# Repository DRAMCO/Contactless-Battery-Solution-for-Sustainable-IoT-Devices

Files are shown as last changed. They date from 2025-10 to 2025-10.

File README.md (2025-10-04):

# Contactless Battery Solution for Sustainable IoT Devices: Assessment of Environmental Impact

Supplementary material for "MDPI Electronics special issue Wireless Power Transfer Systems: Design and Implementation"

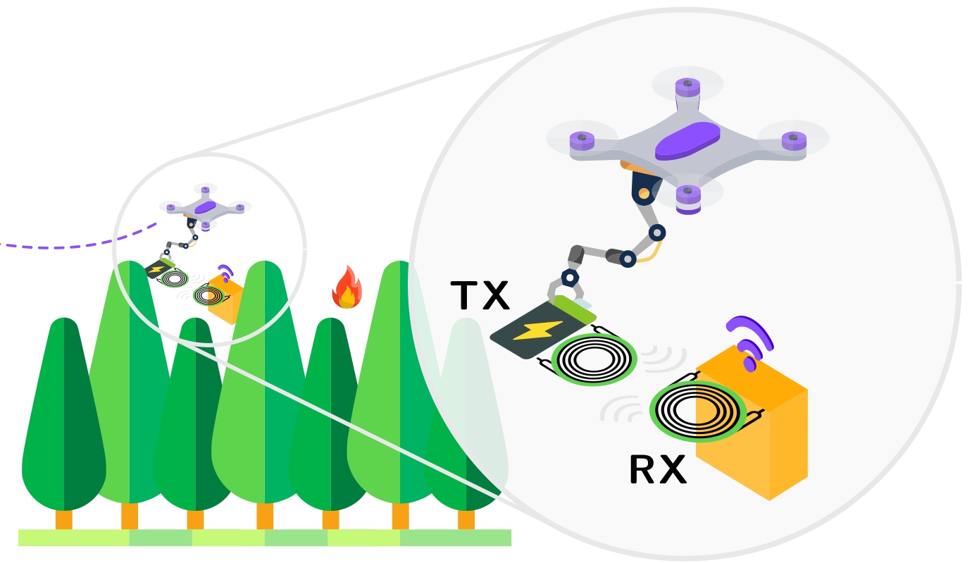
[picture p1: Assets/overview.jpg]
overview


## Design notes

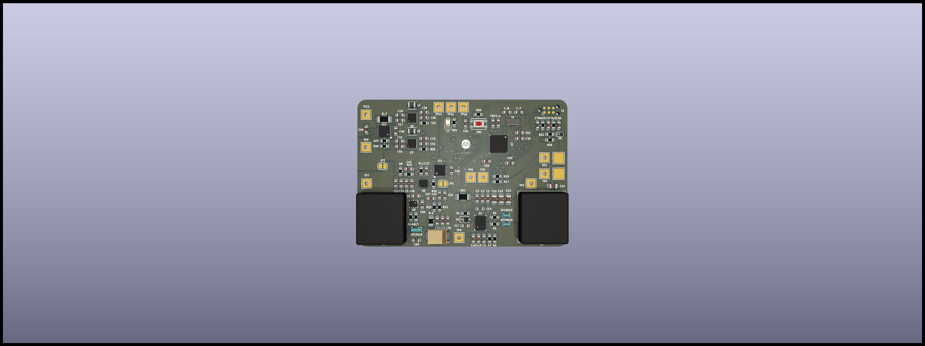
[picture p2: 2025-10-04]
Hardware/wpt_transmitter/driver_prereg_combined.png

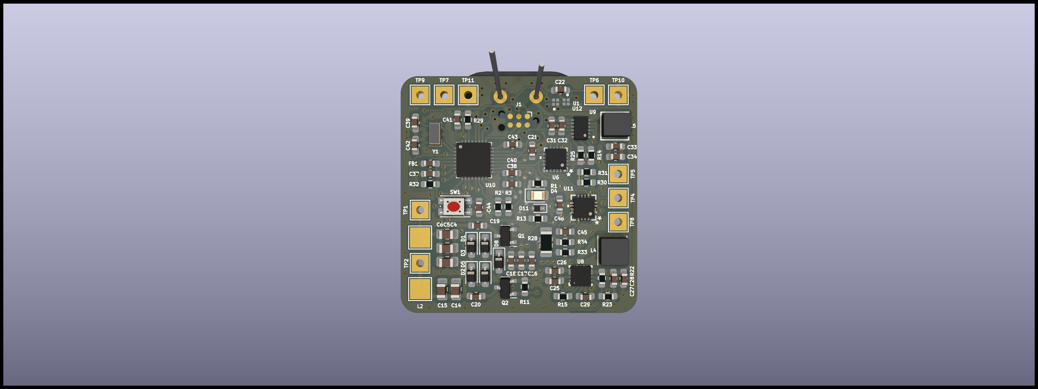
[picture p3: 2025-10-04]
Hardware/wpt_receiver/wpt_receiver.png

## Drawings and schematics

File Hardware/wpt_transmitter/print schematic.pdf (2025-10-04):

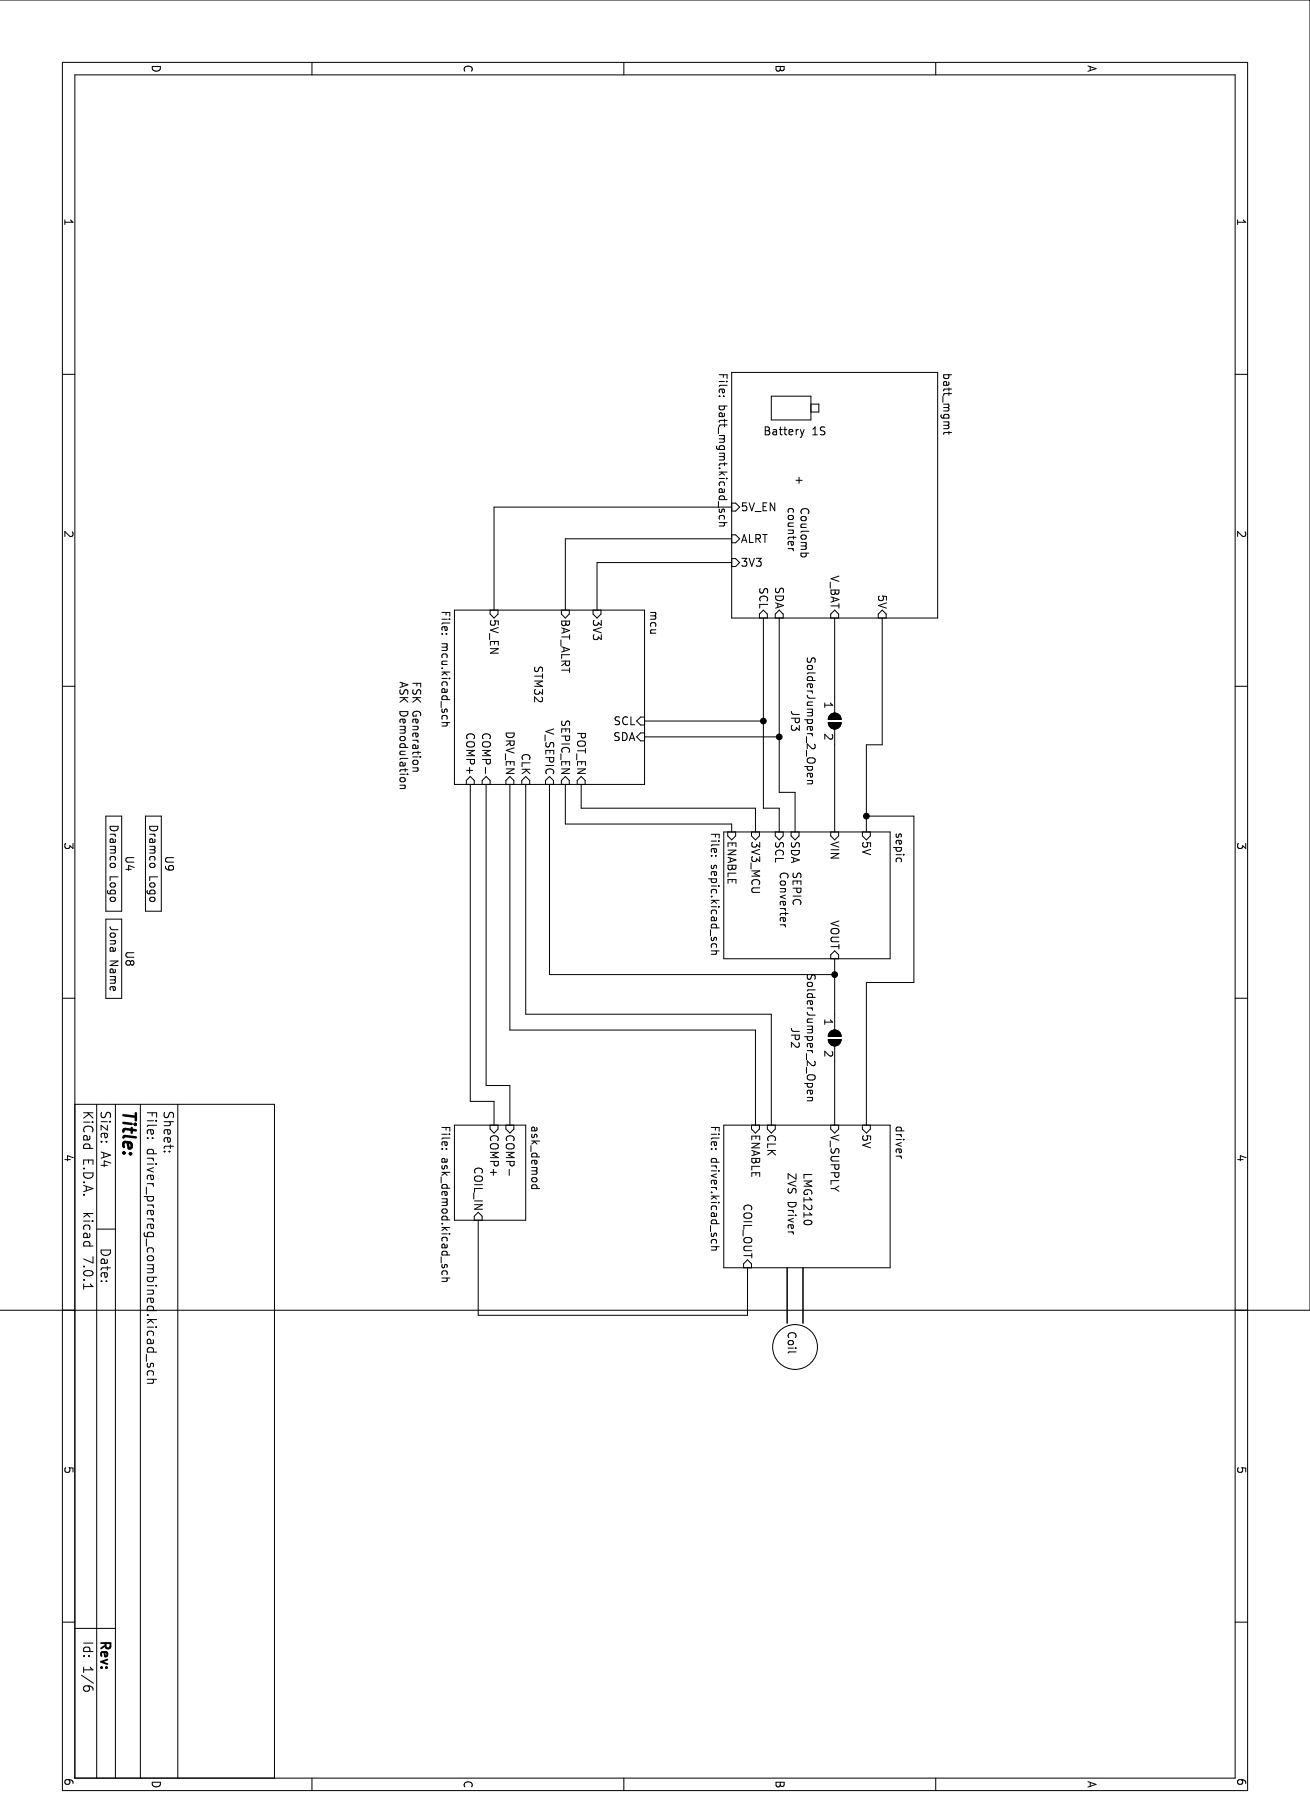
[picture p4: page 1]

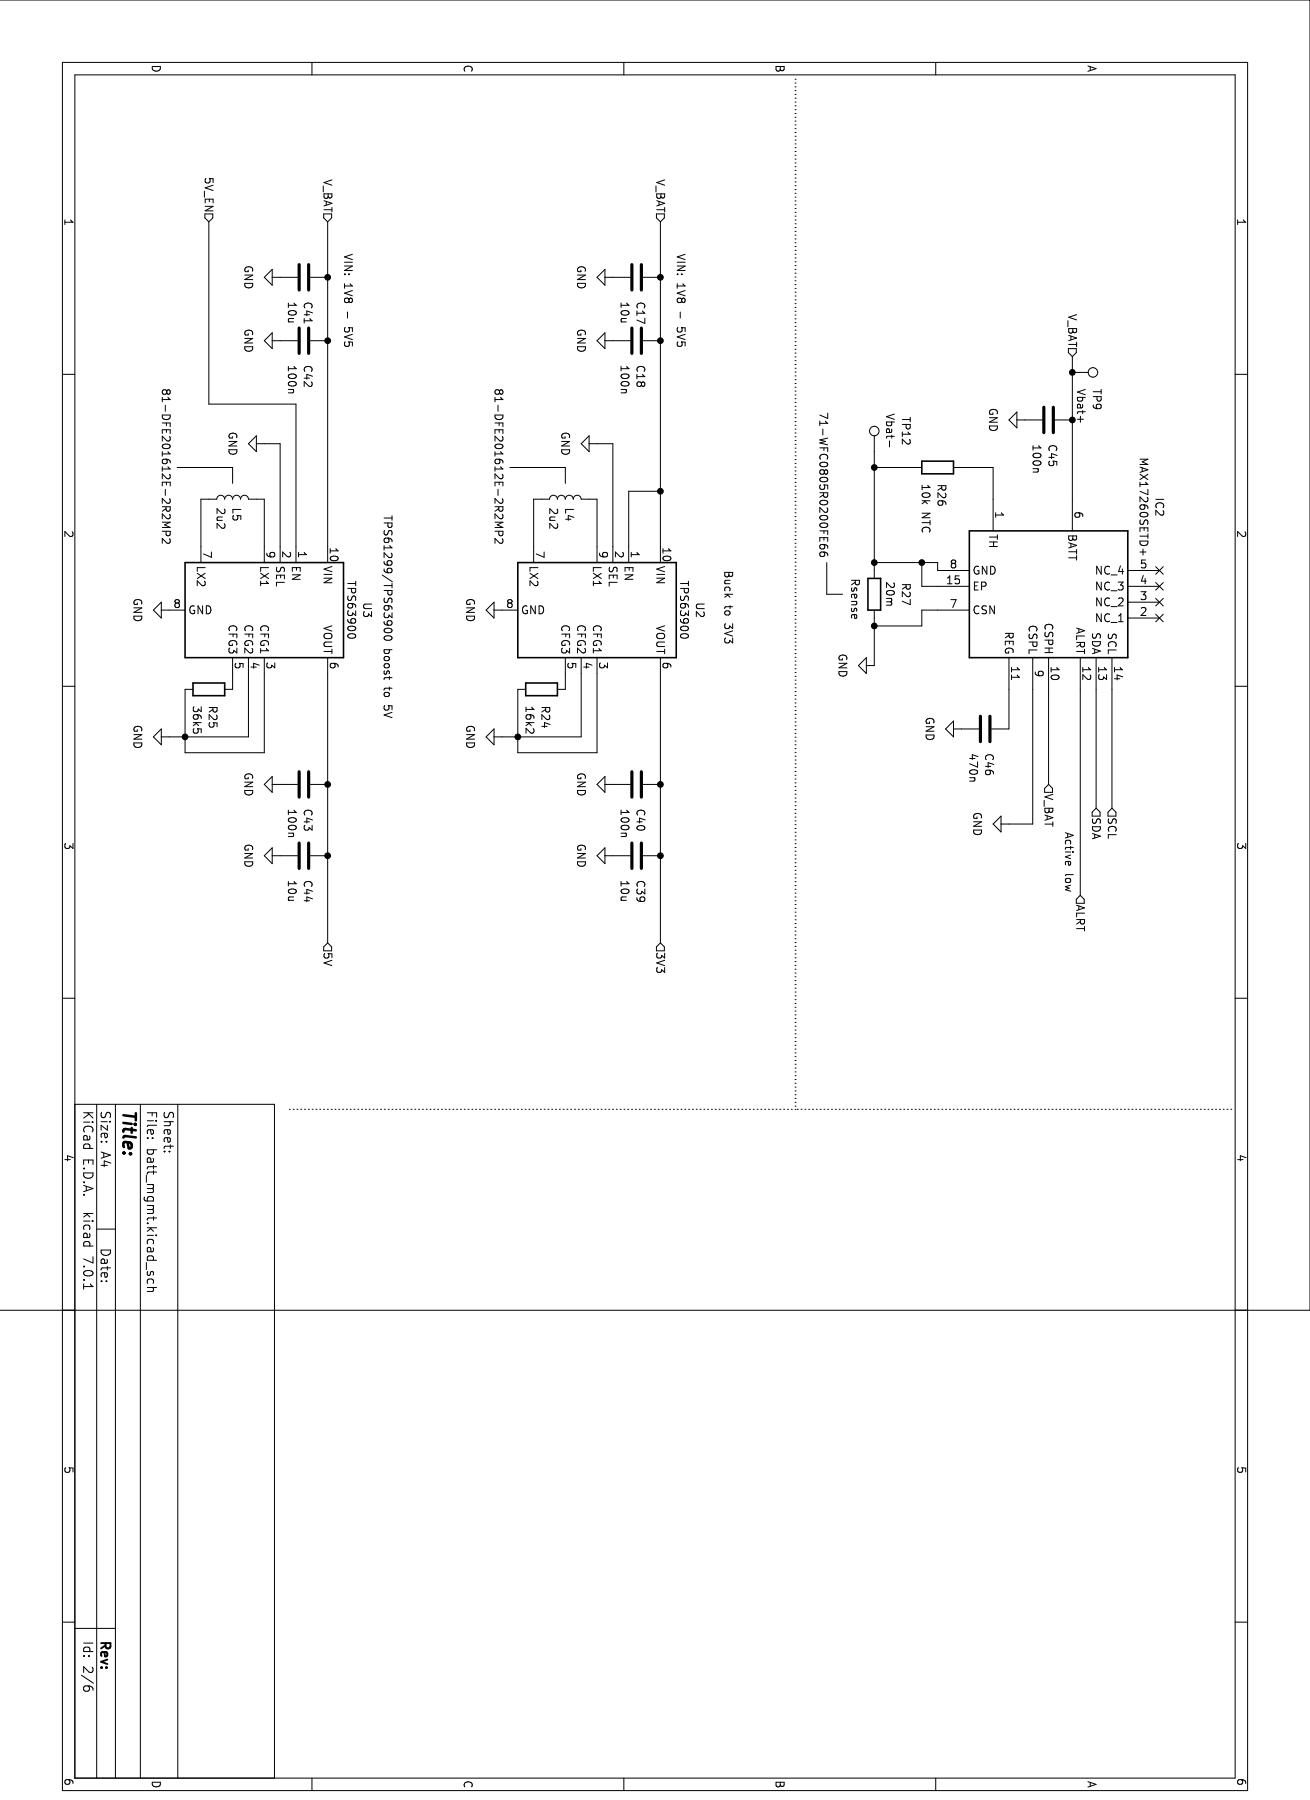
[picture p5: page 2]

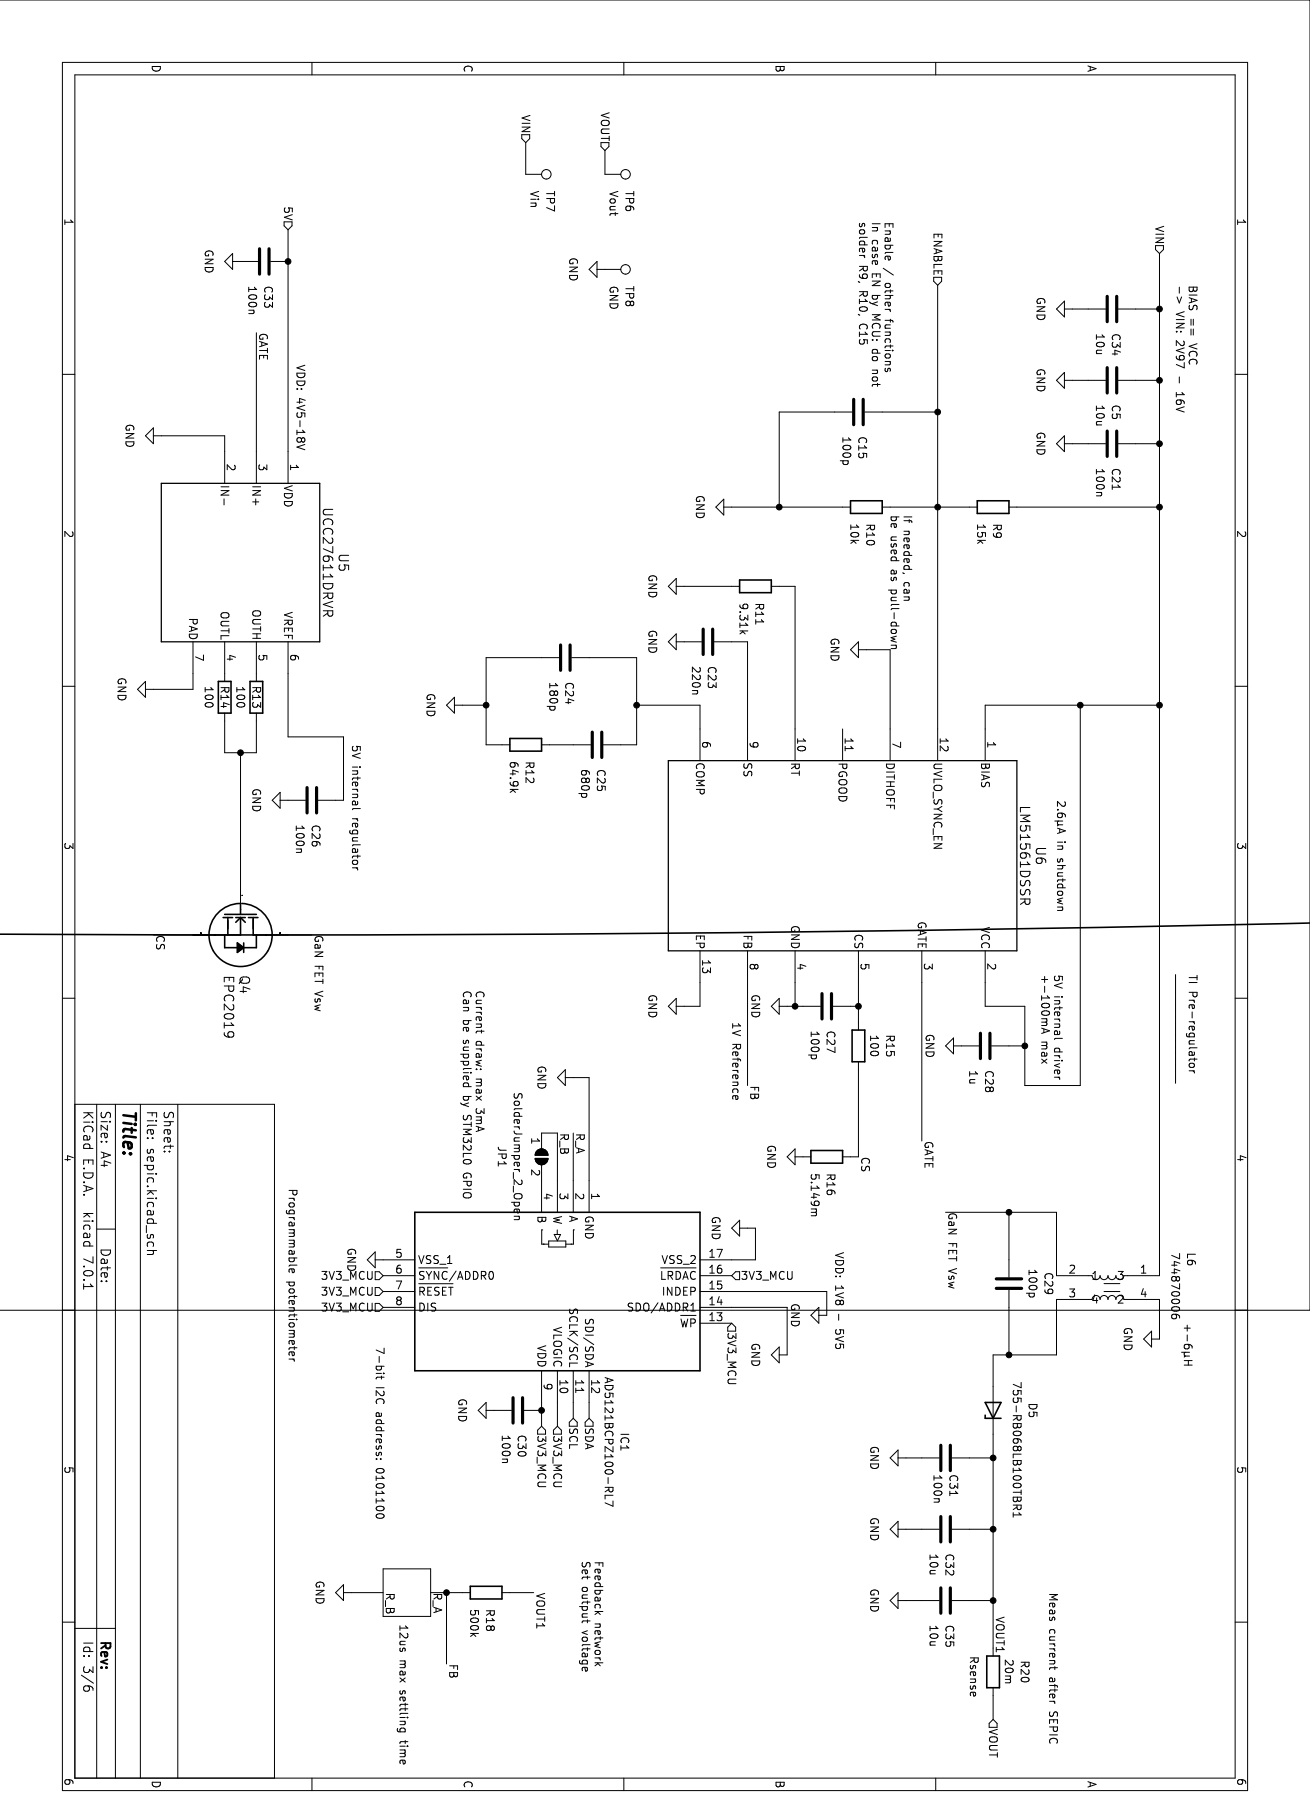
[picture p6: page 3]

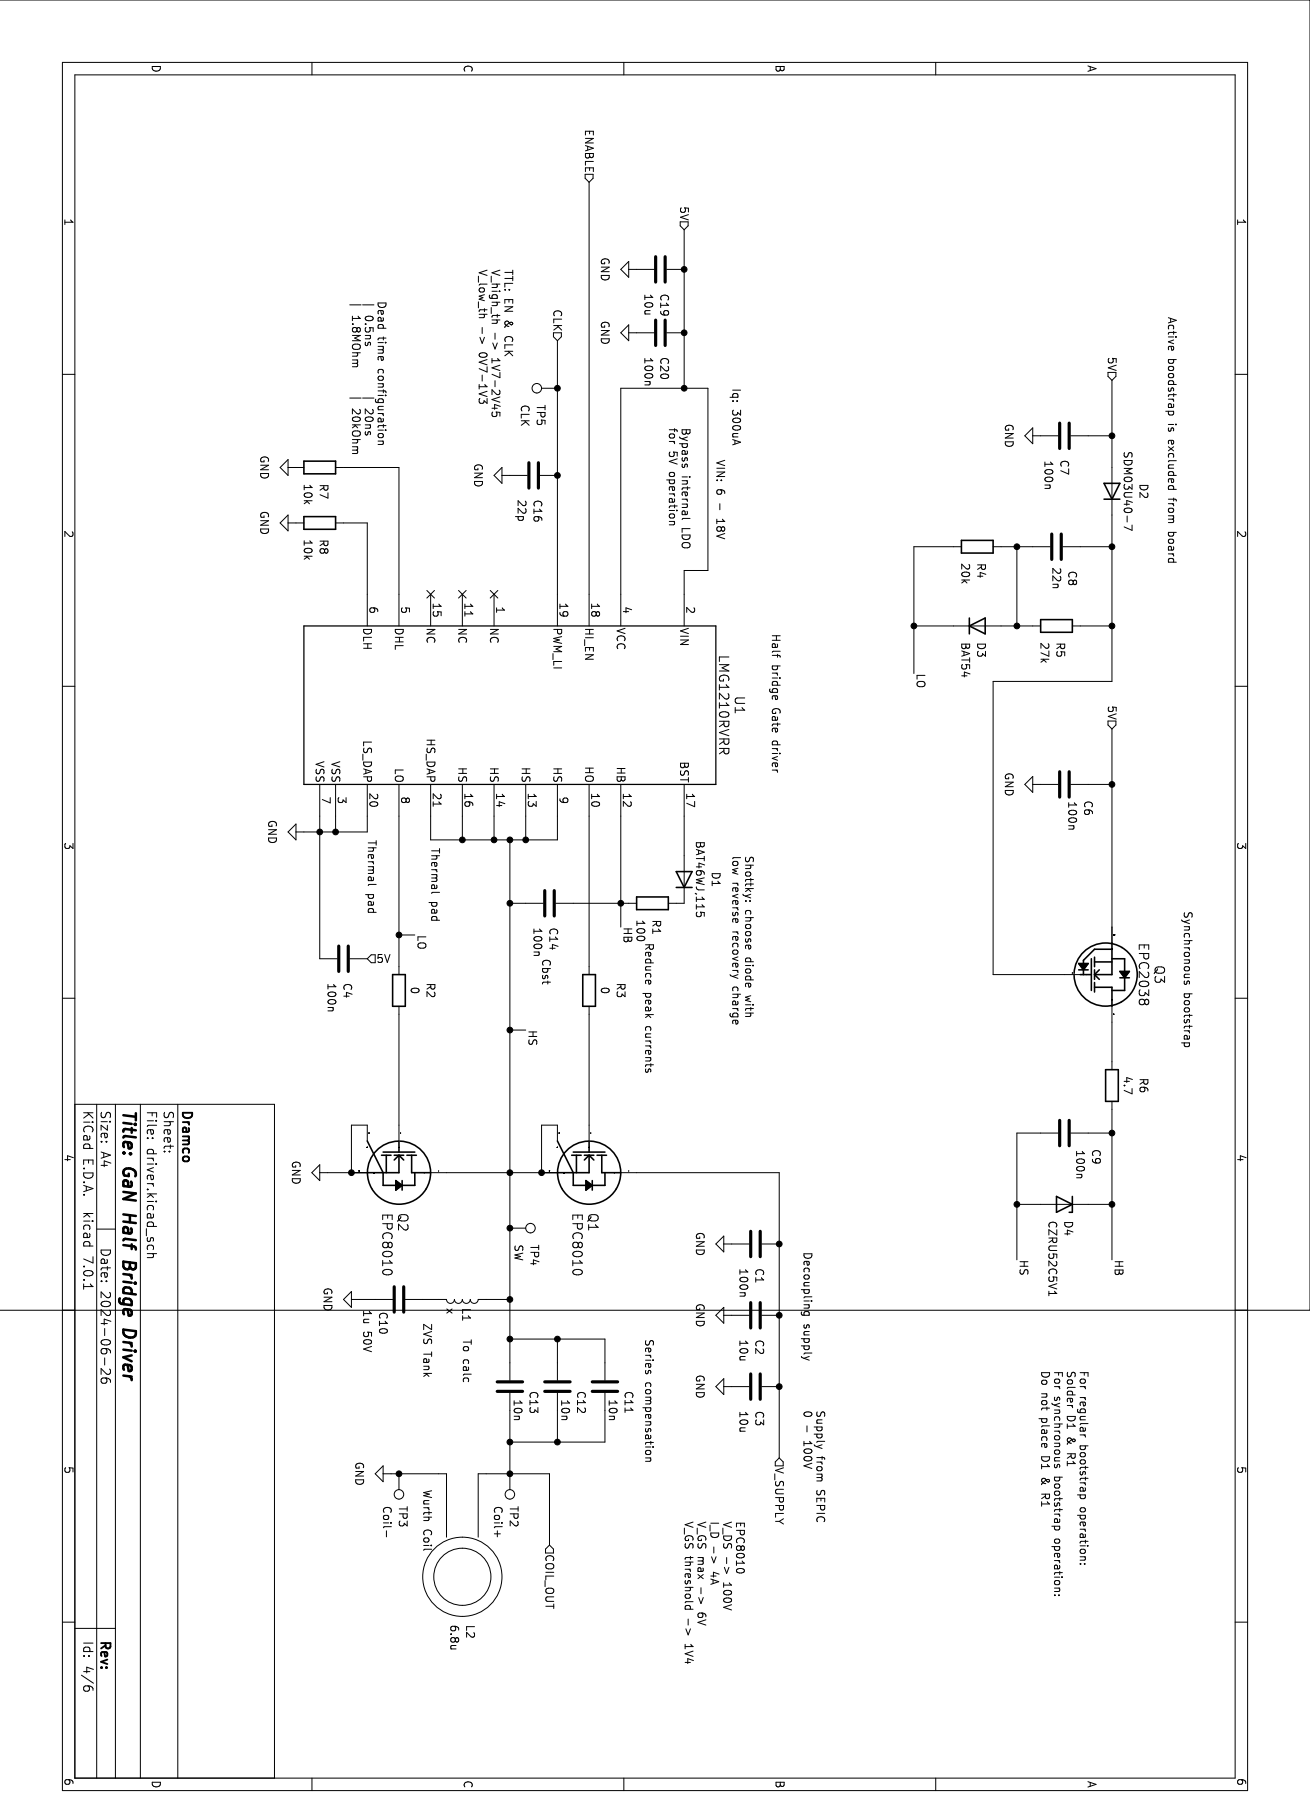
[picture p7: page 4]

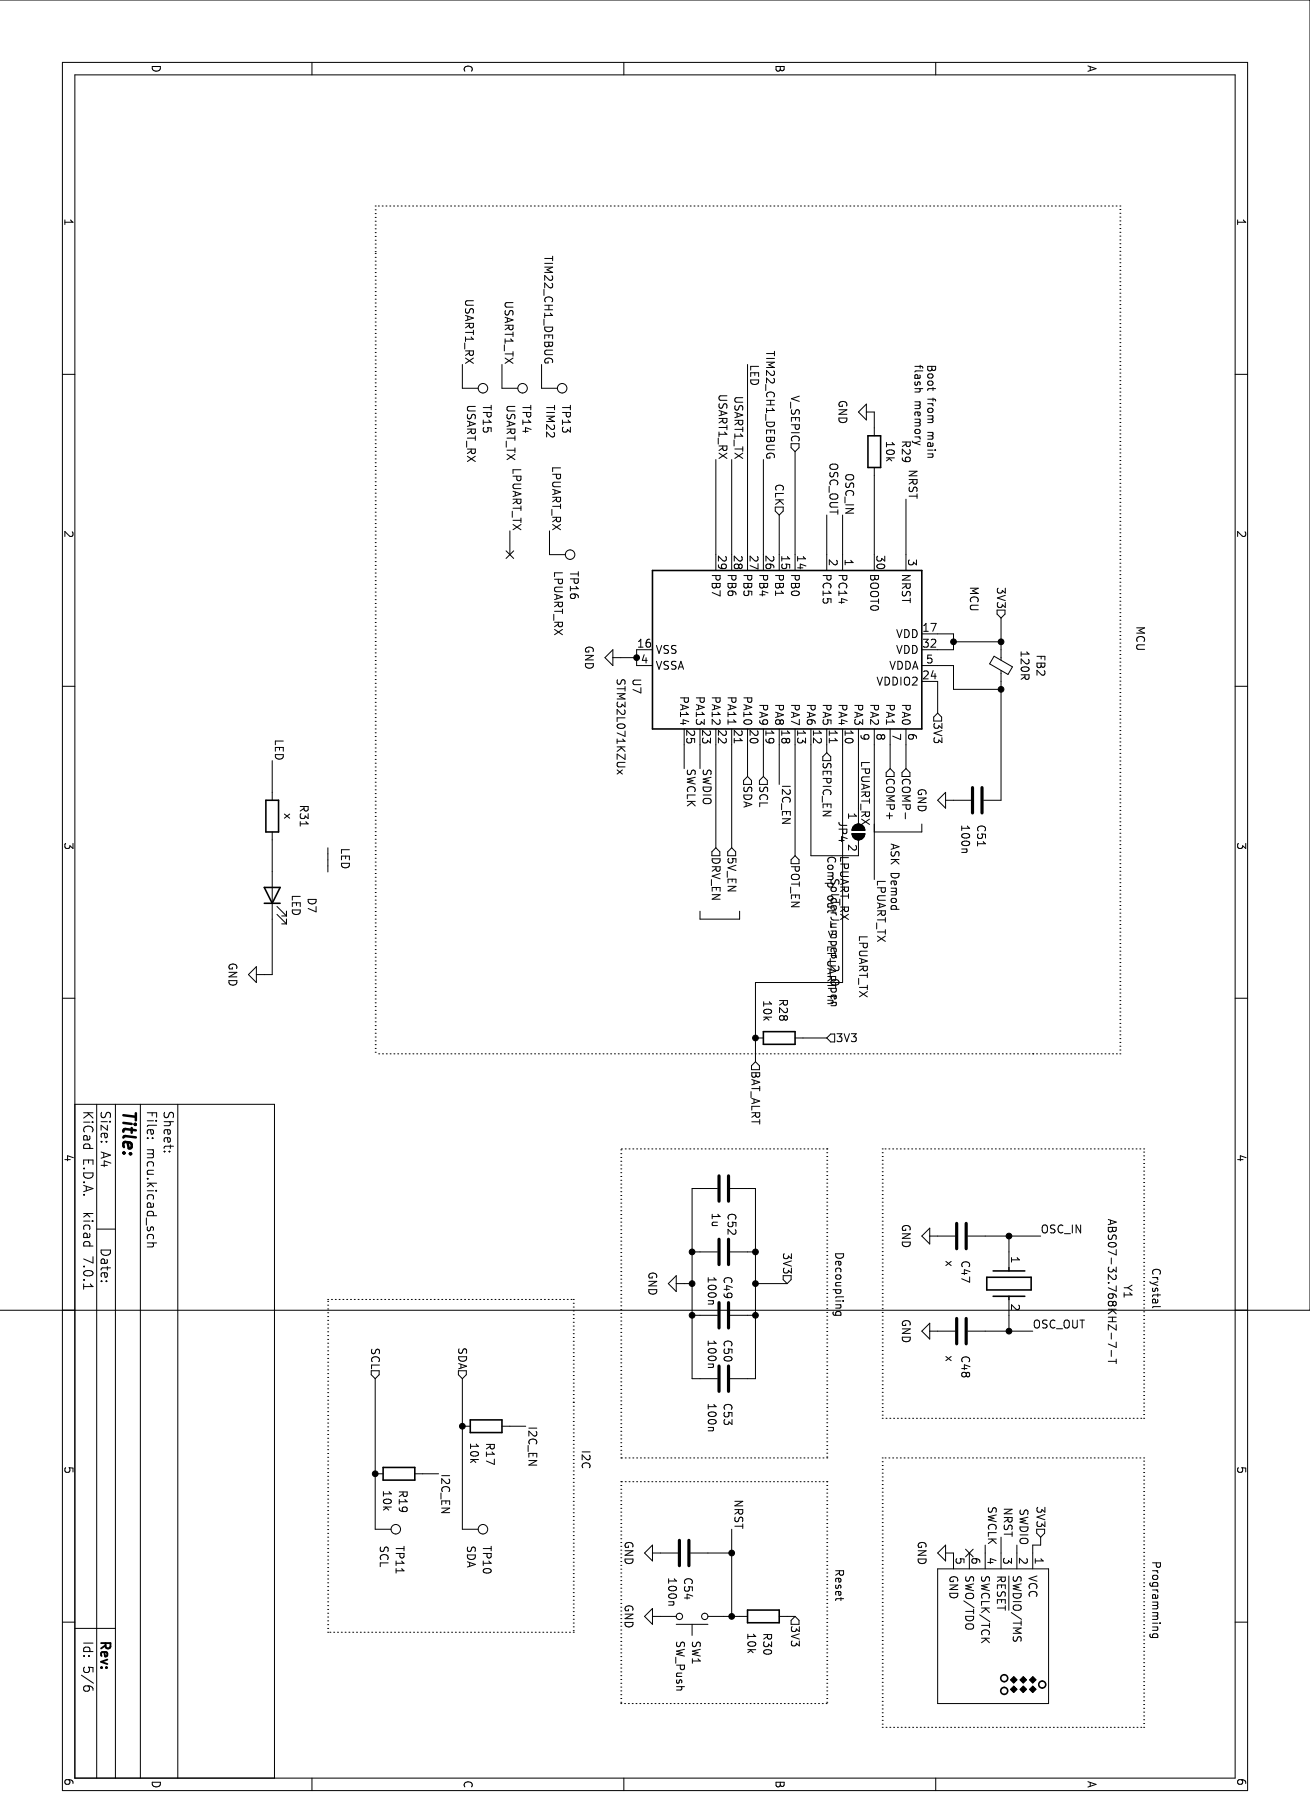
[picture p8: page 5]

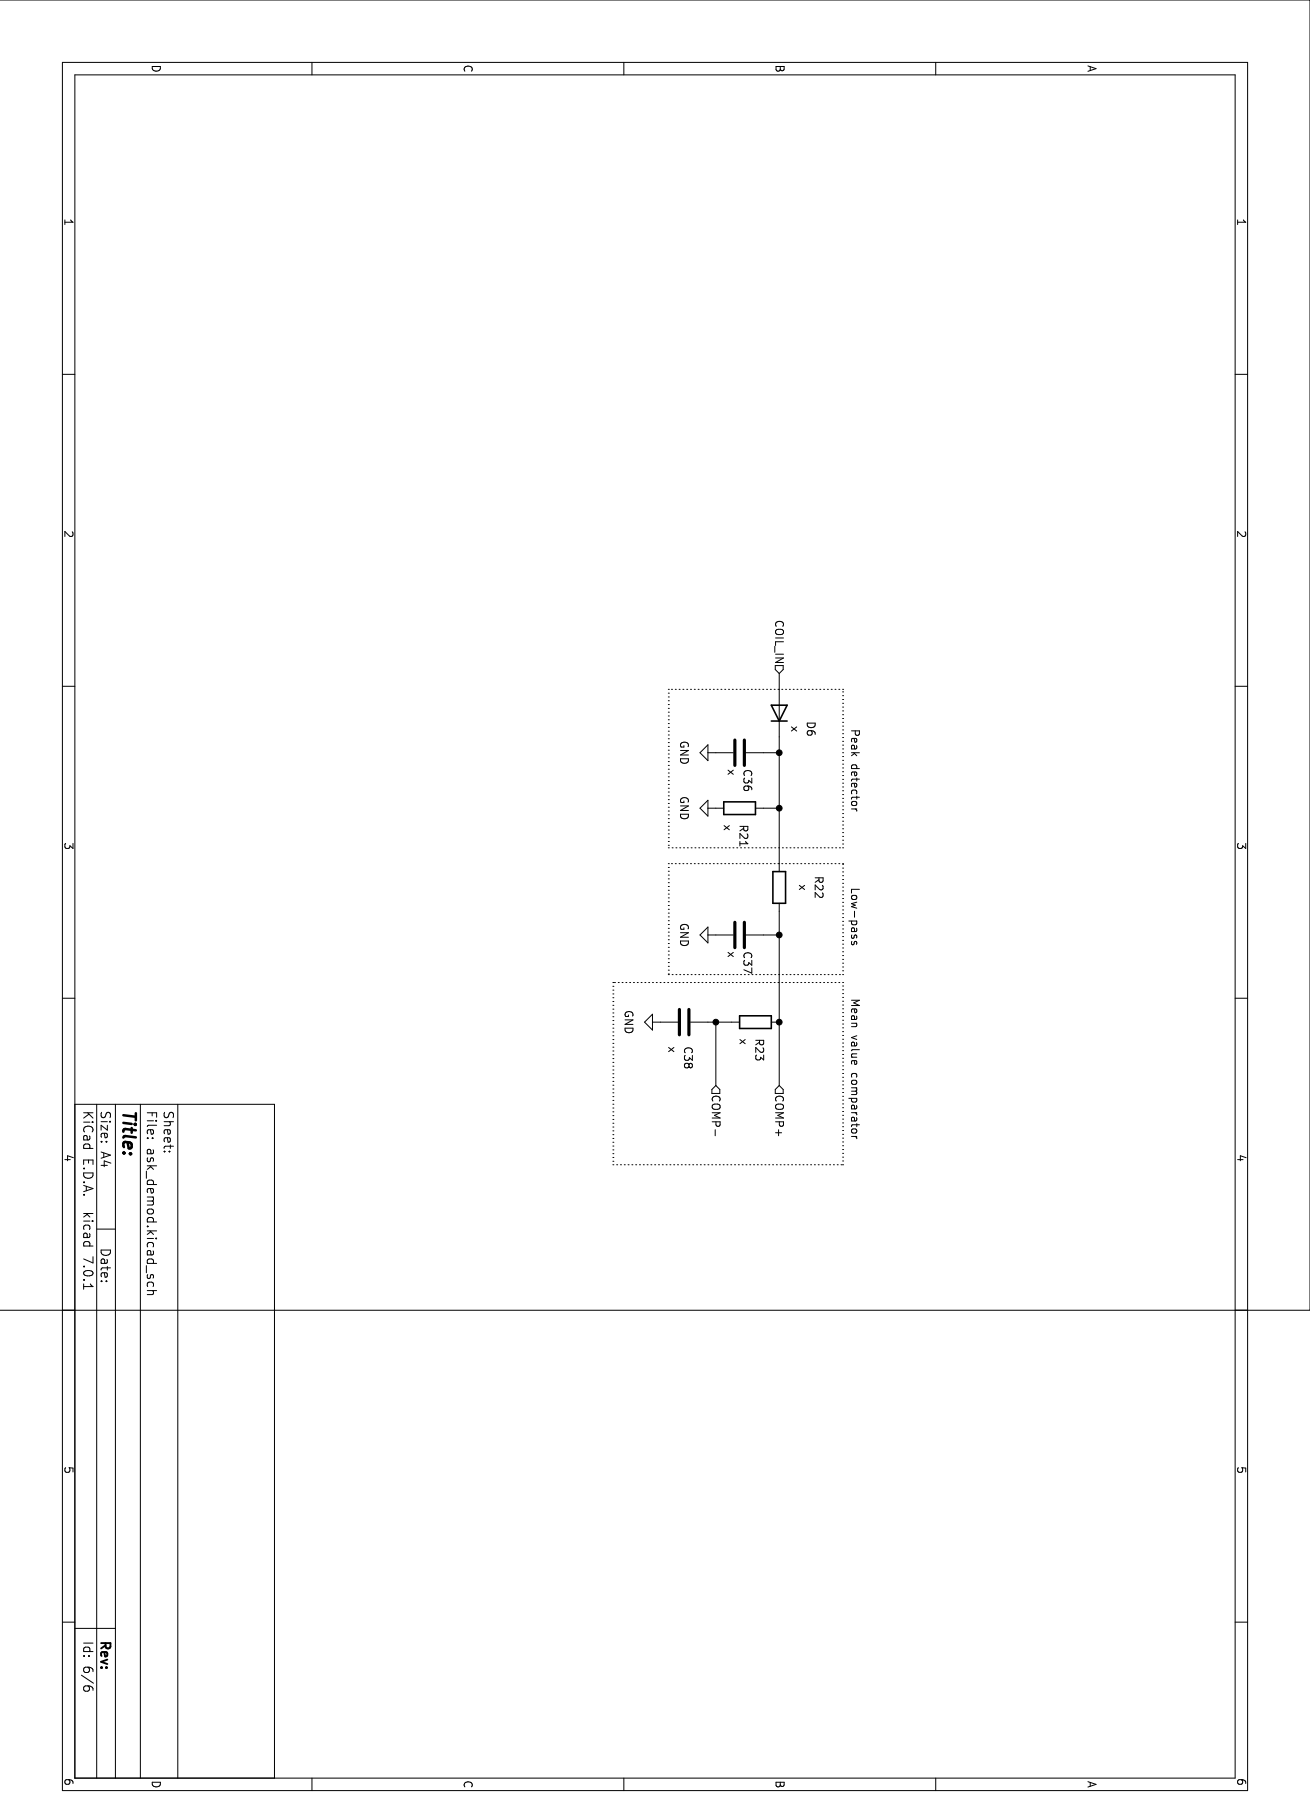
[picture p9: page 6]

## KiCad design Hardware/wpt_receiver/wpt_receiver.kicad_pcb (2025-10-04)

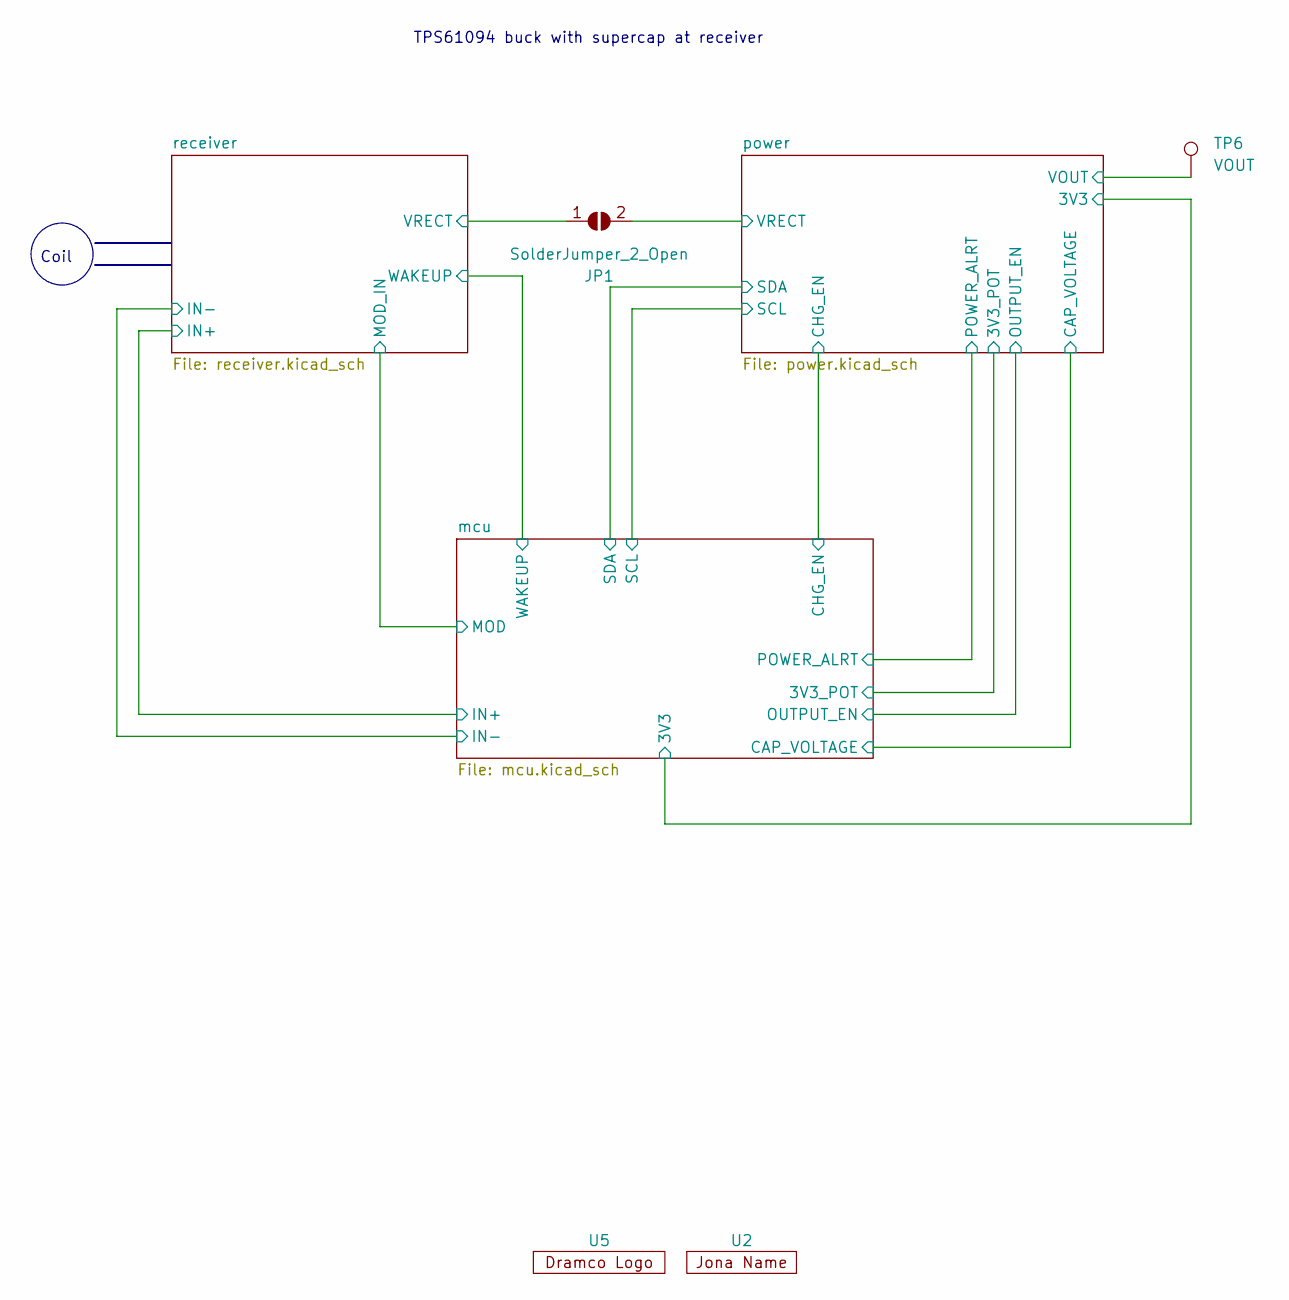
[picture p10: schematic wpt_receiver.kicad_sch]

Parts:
JP1: SolderJumper_2_Open; SolderJumper-2_P1.3mm_Open_RoundedPad1.0x1.5mm
TP6: VOUT; TestPoint_THTPad_2.5x2.5mm_Drill1.2mm
U2: Jona Name
U5: dramco_logo_small

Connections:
/power/VOUT: TP6.1; also elsewhere on the board
unnamed 32: JP1.1 (A); also elsewhere on the board
unnamed 33: JP1.2 (B); also elsewhere on the board

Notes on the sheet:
Coil
TPS61094 buck with supercap at receiver

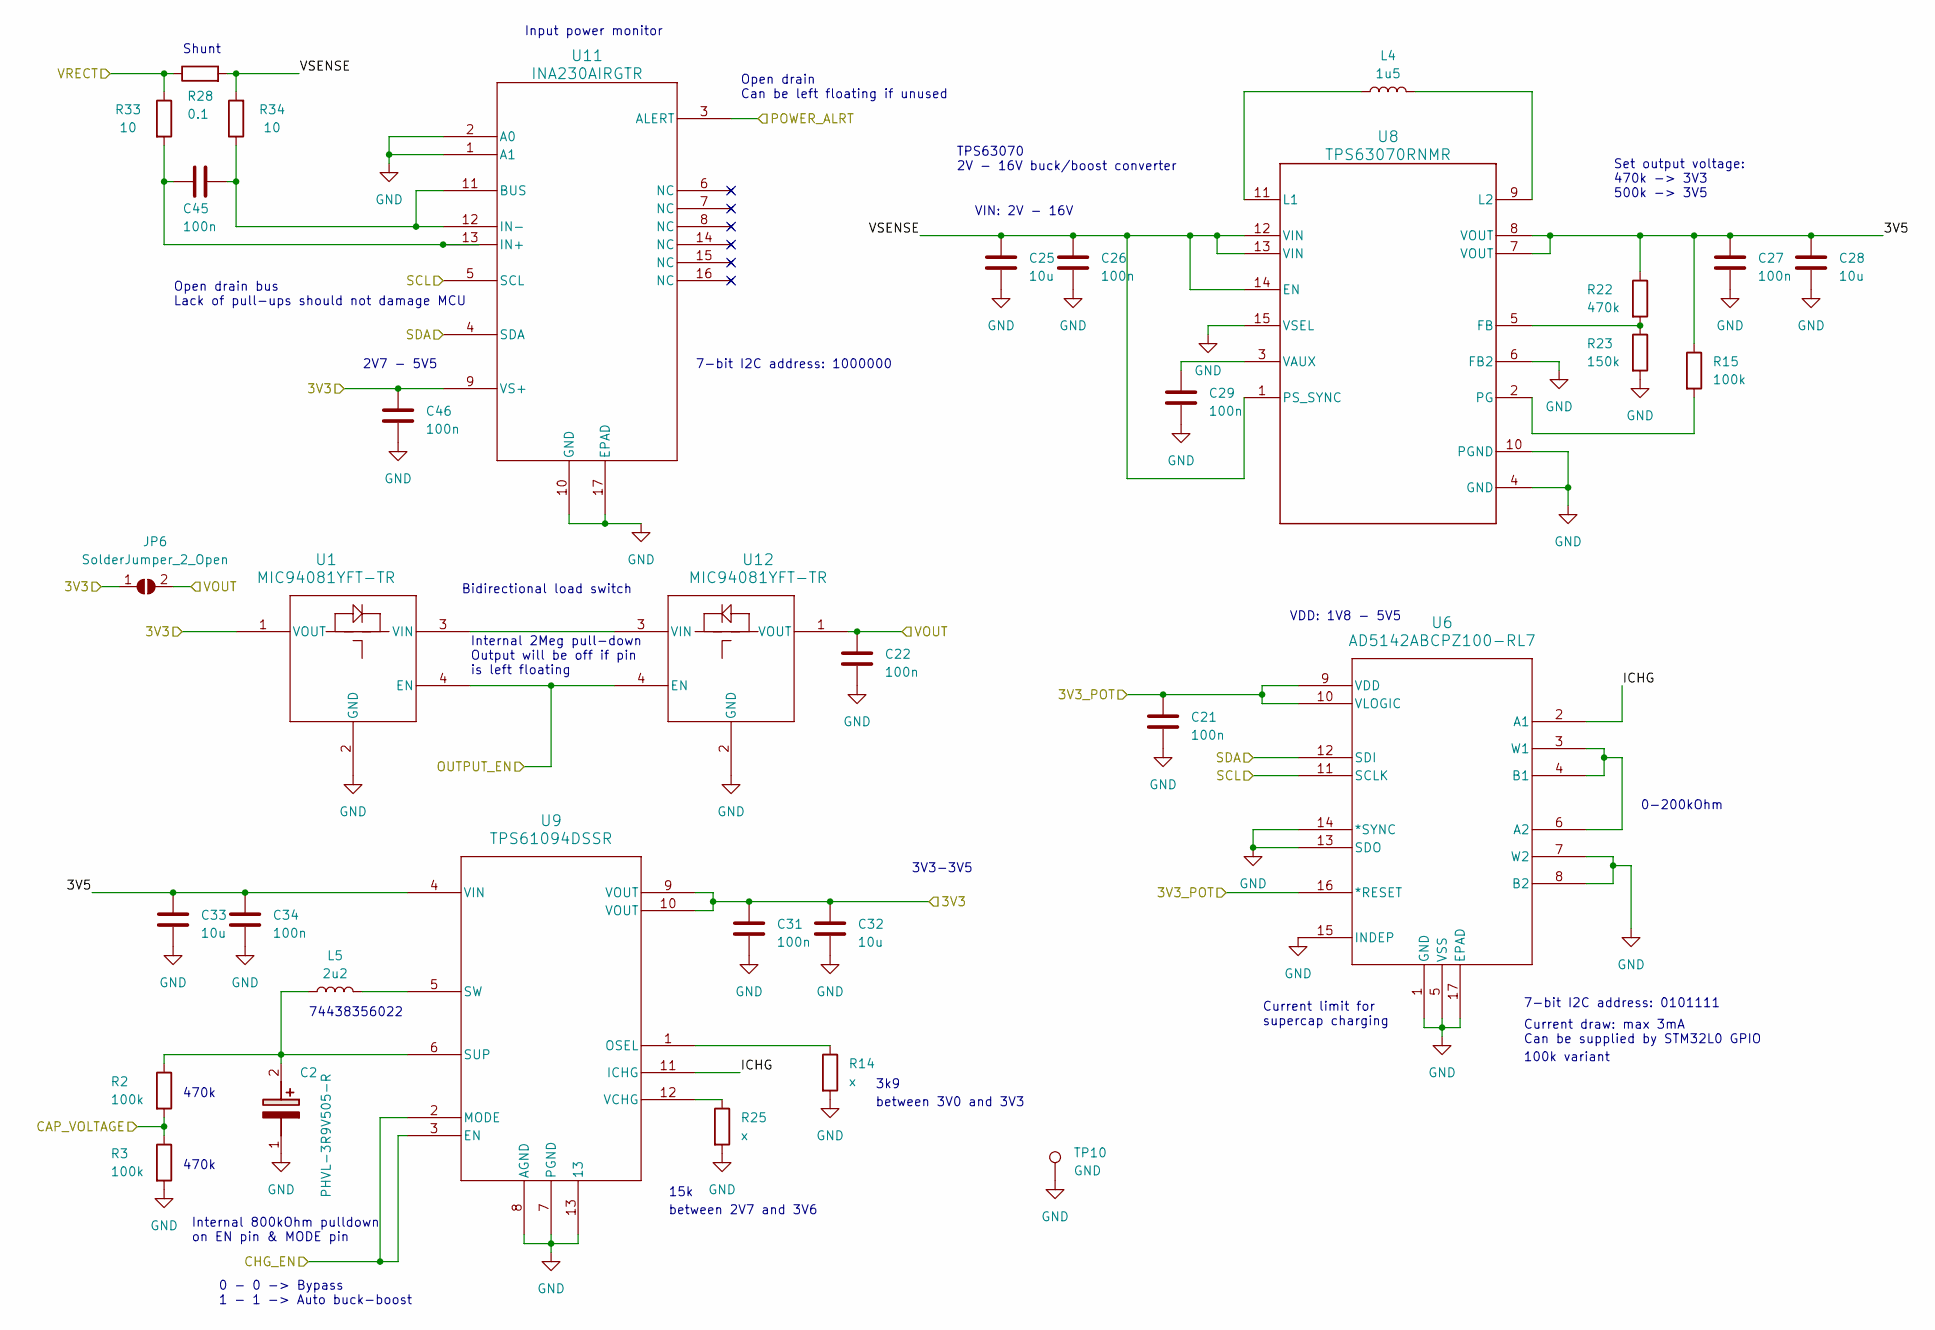
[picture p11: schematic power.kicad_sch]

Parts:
C2: PHVL-3R9V505-R; PHVL3R9V505R; Mouser Part Number 504-PHVL-3R9V505-R
C21, C22, C26, C27, C29, C31, C34, C45, C46: 100n; C_0603_1608Metric_Pad1.08x0.95mm_HandSolder
C25, C28, C32, C33: 10u; C_0603_1608Metric_Pad1.08x0.95mm_HandSolder
JP6: SolderJumper_2_Open; SolderJumper-2_P1.3mm_Open_RoundedPad1.0x1.5mm
L4: 1u5; L_Coilcraft_XxL4020
L5: 2u2; WE-MAPI_4020
R2, R3, R15: 100k; R_0603_1608Metric_Pad0.98x0.95mm_HandSolder
R14, R25: x; R_0603_1608Metric_Pad0.98x0.95mm_HandSolder
R22: 470k; R_0603_1608Metric_Pad0.98x0.95mm_HandSolder
R23: 150k; R_0603_1608Metric_Pad0.98x0.95mm_HandSolder
R28: 0.1; R_1206_3216Metric_Pad1.30x1.75mm_HandSolder
R33, R34: 10; R_0603_1608Metric_Pad0.98x0.95mm_HandSolder
TP10: GND; TestPoint_THTPad_2.5x2.5mm_Drill1.2mm
U1, U12: MIC94081YFT-TR; FTDFN085085-4LD-PL-1_MCH
U6: AD5142ABCPZ100-RL7; CP_16_22_ADI
U8: TPS63070RNMR; RNM0015A
U9: TPS61094DSSR; WSON_94DSSR_TEX
U11: INA230AIRGTR; RGT16_1P7X1P7

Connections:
/mcu/3V3: C31.1, C32.1, C46.1, JP6.1 (A), U1.1 (VOUT), U9.9 (VOUT), U9.10 (VOUT), U11.9 (VS+); also elsewhere on the board
/mcu/3V3_POT: C21.2, U6.9 (VDD), U6.10 (VLOGIC), U6.16 (*RESET); also elsewhere on the board
/mcu/CAP_VOLTAGE: R2.2, R3.1; also elsewhere on the board
/mcu/CHG_EN: U9.2 (MODE), U9.3 (EN); also elsewhere on the board
/mcu/OUTPUT_EN: U1.4 (EN), U12.4 (EN); also elsewhere on the board
/mcu/POWER_ALRT: U11.3 (ALERT); also elsewhere on the board
/mcu/SCL: U6.11 (SCLK), U11.5 (SCL); also elsewhere on the board
/mcu/SDA: U6.12 (SDI), U11.4 (SDA); also elsewhere on the board
/power/3V5: C27.1, C28.1, C33.1, C34.1, R15.1, R22.1, U8.7 (VOUT), U8.8 (VOUT), U9.4 (VIN)
/power/ICHG: U6.2 (A1), U9.11 (ICHG)
/power/VOUT: C22.1, JP6.2 (B), U12.1 (VOUT); also elsewhere on the board
/power/VRECT: R28.1, R33.1; also elsewhere on the board
/power/VSENSE: C25.1, C26.1, R28.2, R34.2, U8.1 (PS_SYNC), U8.12 (VIN), U8.13 (VIN), U8.14 (EN)
GND: C2.1 (-), C21.1, C22.2, C25.2, C26.2, C27.2, C28.2, C29.2, C31.2, C32.2, C33.2, C34.2, C46.2, R3.2, R14.2, R23.2, R25.2, TP10.1, U1.2 (GND), U6.1 (GND), U6.5 (VSS), U6.7 (W2), U6.8 (B2), U6.13 (SDO), U6.14 (*SYNC), U6.15 (INDEP), U6.17 (EPAD), U8.4 (GND), U8.6 (FB2), U8.10 (PGND), U8.15 (VSEL), U9.7 (PGND), U9.8 (AGND), U9.13, U11.1 (A1), U11.2 (A0), U11.10 (GND), U11.17 (EPAD), U12.2 (GND); also elsewhere on the board
unnamed: C2.2 (+), L5.1, R2.1, U9.6 (SUP)
unnamed: U1.3 (VIN), U12.3 (VIN)
unnamed: U6.3 (W1), U6.4 (B1), U6.6 (A2)
unnamed: R22.2, R23.1, U8.5 (FB)
unnamed: L4.1, U8.11 (L1)
unnamed: L4.2, U8.9 (L2)
unnamed: R15.2, U8.2 (PG)
unnamed: C29.1, U8.3 (VAUX)
unnamed: R14.1, U9.1 (OSEL)
unnamed: L5.2, U9.5 (SW)
unnamed: R25.1, U9.12 (VCHG)
unnamed: C45.1, R34.1, U11.11 (BUS), U11.12 (IN-)
unnamed: C45.2, R33.2, U11.13 (IN+)

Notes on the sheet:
7-bit I2C address: 0101111
between 2V7 and 3V6
0-200kOhm
15k
Internal 2Meg pull-down Output will be off if pin is left floating
3k9
Bidirectional load switch
Current draw: max 3mA Can be supplied by STM32L0 GPIO
VIN: 2V - 16V
between 3V0 and 3V3
Input power monitor
Set output voltage: 470k -> 3V3 500k -> 3V5
Open drain Can be left floating if unused
470k
Internal 800kOhm pulldown on EN pin & MODE pin
74438356022
Shunt
TPS63070 2V - 16V buck/boost converter
VDD: 1V8 - 5V5
Current limit for supercap charging
Open drain bus Lack of pull-ups should not damage MCU
0 - 0 -> Bypass 1 - 1 -> Auto buck-boost
2V7 - 5V5
3V3-3V5
100k variant
7-bit I2C address: 1000000

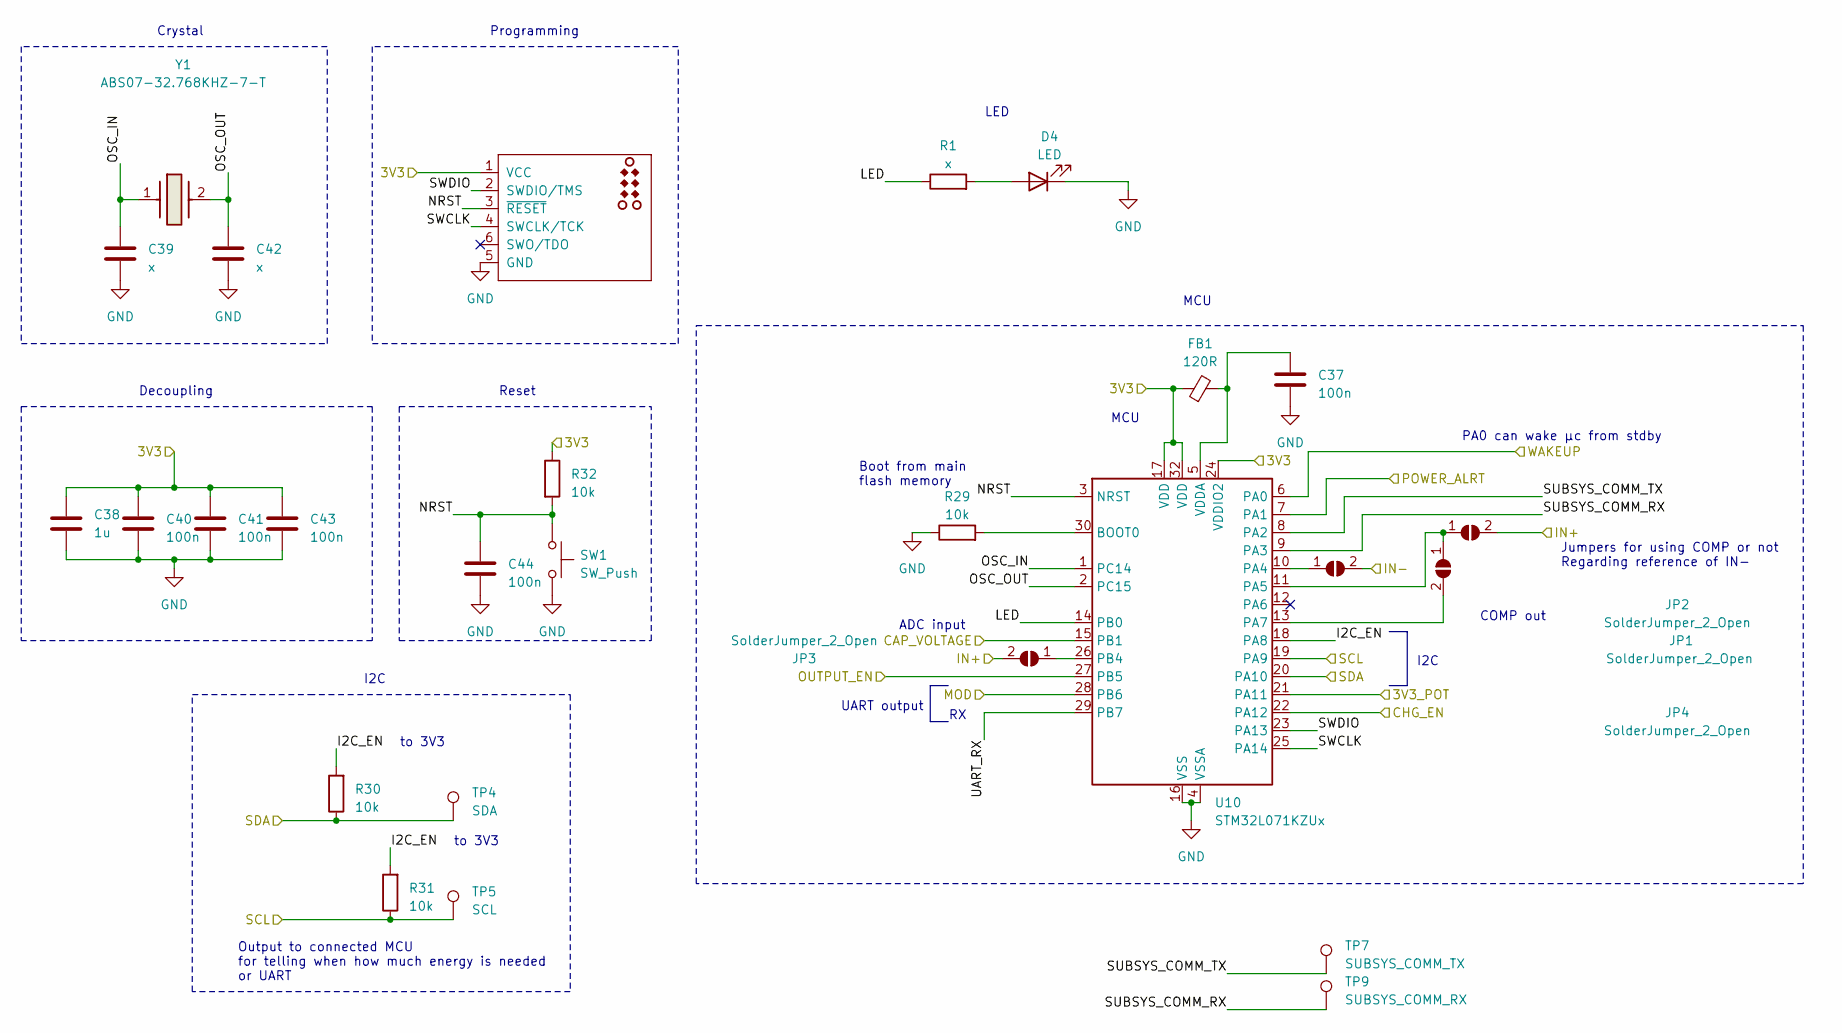
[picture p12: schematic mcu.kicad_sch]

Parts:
C37, C40, C41, C43, C44: 100n; C_0603_1608Metric_Pad1.08x0.95mm_HandSolder
C38: 1u; C_0603_1608Metric_Pad1.08x0.95mm_HandSolder
C39, C42: x; C_0603_1608Metric_Pad1.08x0.95mm_HandSolder
D4: LED; LED_0805_2012Metric_Pad1.15x1.40mm_HandSolder
FB1: 120R; C_0603_1608Metric_Pad1.08x0.95mm_HandSolder
J1: TC2030_SWD-MCP-NL; Tag-Connect_TC2030-IDC-NL_2x03_P1.27mm_Vertical
JP1, JP2, JP3, JP4: SolderJumper_2_Open; SolderJumper-2_P1.3mm_Open_RoundedPad1.0x1.5mm
R1: x; R_0603_1608Metric_Pad0.98x0.95mm_HandSolder
R29, R30, R31, R32: 10k; R_0603_1608Metric_Pad0.98x0.95mm_HandSolder
SW1: SW_Push; SW_Push_1P1T_NO_CK_KMR2
TP4: SDA; TestPoint_THTPad_2.5x2.5mm_Drill1.2mm
TP5: SCL; TestPoint_THTPad_2.5x2.5mm_Drill1.2mm
TP7: SUBSYS_COMM_TX; TestPoint_THTPad_2.5x2.5mm_Drill1.2mm
TP9: SUBSYS_COMM_RX; TestPoint_THTPad_2.5x2.5mm_Drill1.2mm
U10: STM32L071KZUx; QFN-32-1EP_5x5mm_P0.5mm_EP3.45x3.45mm
Y1: ABS07-32.768KHZ-7-T; ABS07; Mouser Part Number 815-ABS07-32.768K7T

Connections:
/mcu/3V3: C38.1, C40.1, C41.1, C43.1, FB1.1, J1.1 (VCC), R32.1, U10.17 (VDD), U10.24 (VDDIO2), U10.32 (VDD); also elsewhere on the board
/mcu/3V3_POT: U10.21 (PA11); also elsewhere on the board
/mcu/CAP_VOLTAGE: U10.15 (PB1); also elsewhere on the board
/mcu/CHG_EN: U10.22 (PA12); also elsewhere on the board
/mcu/I2C_EN: R30.2, R31.2, U10.18 (PA8)
/mcu/IN+: JP2.2 (B), JP3.2 (B); also elsewhere on the board
/mcu/LED: R1.1, U10.14 (PB0)
/mcu/MOD: U10.28 (PB6); also elsewhere on the board
/mcu/NRST: C44.1, J1.3 (~RESET), R32.2, SW1.1, U10.3 (NRST)
/mcu/OSC_IN: C39.1, U10.1 (PC14), Y1.1
/mcu/OSC_OUT: C42.1, U10.2 (PC15), Y1.2
/mcu/OUTPUT_EN: U10.27 (PB5); also elsewhere on the board
/mcu/POWER_ALRT: U10.7 (PA1); also elsewhere on the board
/mcu/SCL: R31.1, TP5.1, U10.19 (PA9); also elsewhere on the board
/mcu/SDA: R30.1, TP4.1, U10.20 (PA10); also elsewhere on the board
/mcu/SUBSYS_COMM_RX: TP9.1, U10.9 (PA3)
/mcu/SUBSYS_COMM_TX: TP7.1, U10.8 (PA2)
/mcu/SWCLK: J1.4 (SWCLK/TCK), U10.25 (PA14)
/mcu/SWDIO: J1.2 (SWDIO/TMS), U10.23 (PA13)
/mcu/UART_RX: U10.29 (PB7)
/mcu/WAKEUP: U10.6 (PA0); also elsewhere on the board
/receiver/COIL-: JP4.2 (B); also elsewhere on the board
GND: C37.2, C38.2, C39.2, C40.2, C41.2, C42.2, C43.2, C44.2, D4.1 (K), J1.5 (GND), R29.1, SW1.2, U10.4 (VSSA), U10.16 (VSS), U10.31 (VSS), U10.33 (VSS); also elsewhere on the board
unnamed: D4.2 (A), R1.2
unnamed: JP1.1 (A), JP2.1 (A), U10.11 (PA5)
unnamed: JP1.2 (B), U10.13 (PA7)
unnamed: JP3.1 (A), U10.26 (PB4)
unnamed: JP4.1 (A), U10.10 (PA4)
unnamed: R29.2, U10.30 (BOOT0)
unnamed: C37.1, FB1.2, U10.5 (VDDA)

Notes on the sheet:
I2C
Crystal
MCU
PA0 can wake µc from stdby
ADC input
Decoupling
Programming
Jumpers for using COMP or not Regarding reference of IN-
to 3V3
Reset
Boot from main flash memory
Output to connected MCU for telling when how much energy is needed or UART
LED
COMP out
UART output

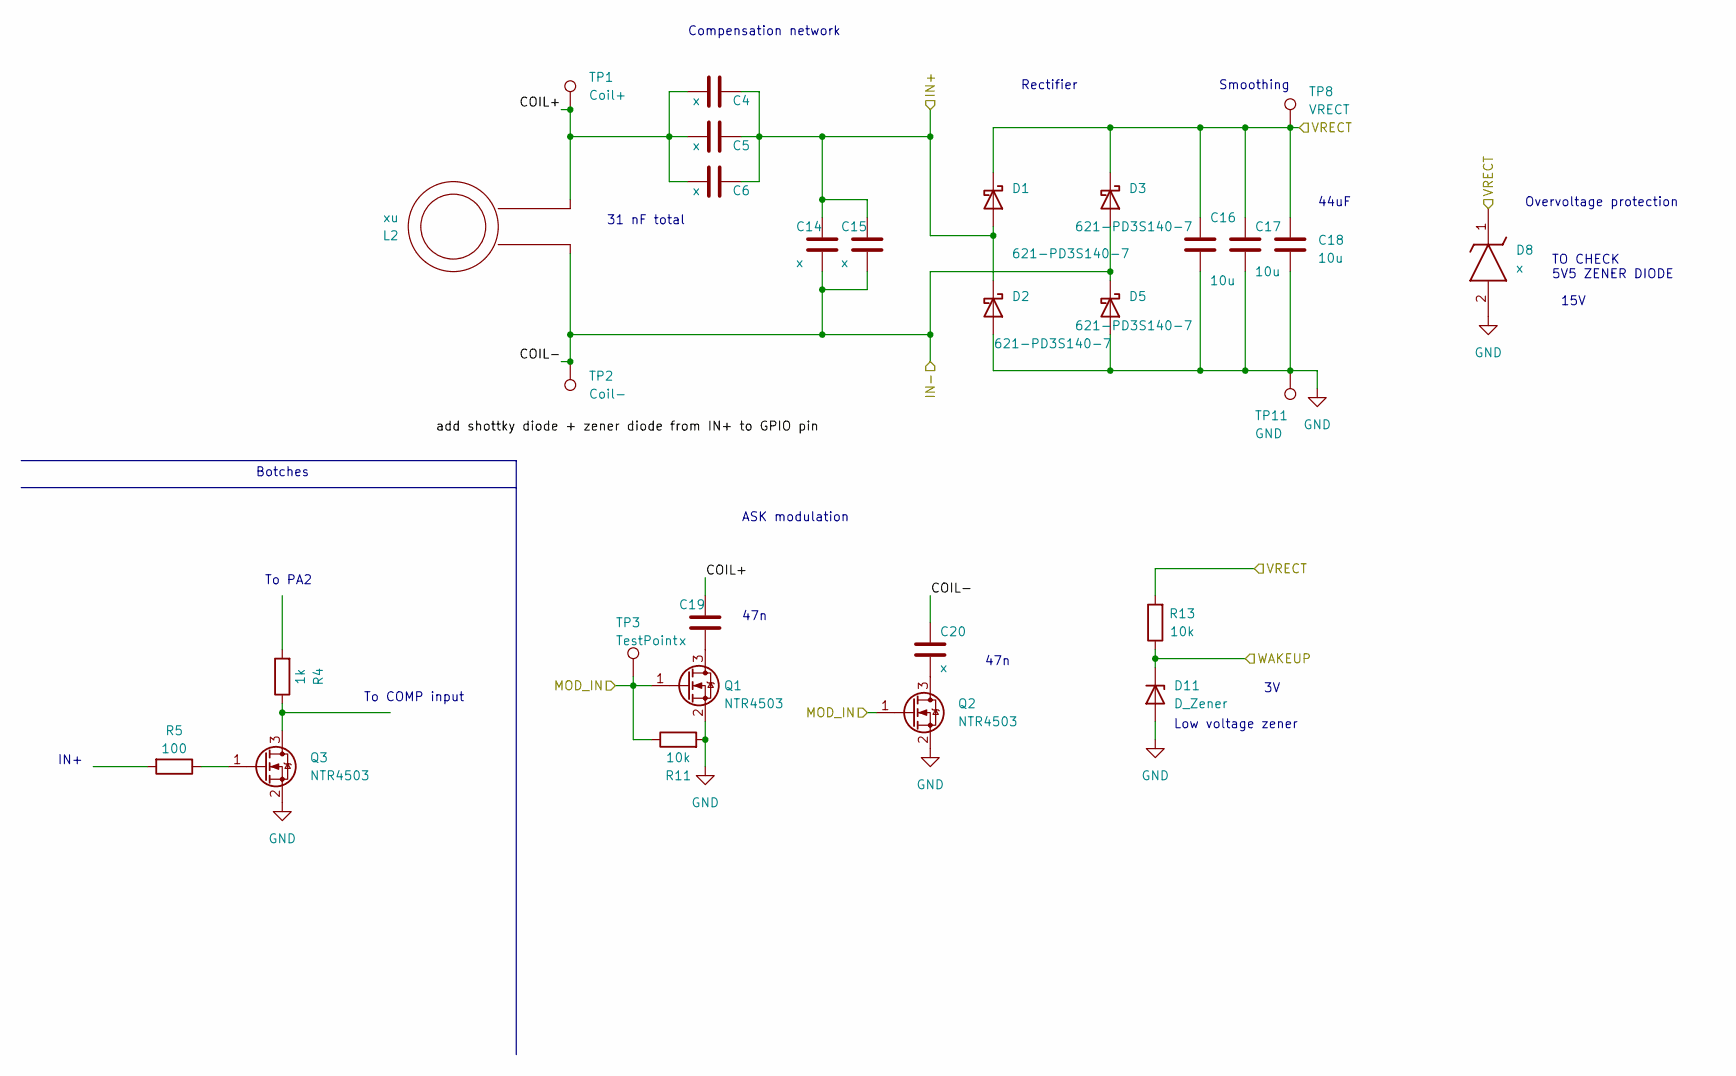
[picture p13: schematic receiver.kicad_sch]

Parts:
C4, C5, C6, C14, C15: x; C_0805_2012Metric_Pad1.18x1.45mm_HandSolder
C16, C17, C18: 10u; C_0603_1608Metric_Pad1.08x0.95mm_HandSolder
C19, C20: x; C_0603_1608Metric_Pad1.08x0.95mm_HandSolder
D1, D2, D3, D5: 621-PD3S140-7; D_SOD-323_HandSoldering
D8: x; D_SOD-323_HandSoldering; Mouser Part Number 621-D24V0S1U2TQ-7
D11: D_Zener; D_SOD-523
L2: xu; Wurth Coil Connector
Q1, Q2, Q3: NTR4503; SOT-23
R4: 1k; R_0603_1608Metric_Pad0.98x0.95mm_HandSolder
R5: 100; R_0603_1608Metric_Pad0.98x0.95mm_HandSolder
R11, R13: 10k; R_0603_1608Metric_Pad0.98x0.95mm_HandSolder
TP1: Coil+; TestPoint_THTPad_2.5x2.5mm_Drill1.2mm
TP2: Coil-; TestPoint_THTPad_2.5x2.5mm_Drill1.2mm
TP3: TestPoint; TestPoint_Pad_2.5x2.5mm
TP8: VRECT; TestPoint_THTPad_2.5x2.5mm_Drill1.2mm
TP11: GND; TestPoint_THTPad_2.5x2.5mm_Drill1.2mm

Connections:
/mcu/IN+: C4.2, C5.2, C6.2, C14.1, C15.1, D1.2 (A), D2.1 (K); also elsewhere on the board
/mcu/MOD: Q1.1 (G), Q2.1 (G), R11.1, TP3.1; also elsewhere on the board
/mcu/WAKEUP: D11.1 (K), R13.1; also elsewhere on the board
/receiver/COIL+: C4.1, C5.1, C6.1, C19.1, L2.2, TP1.1
/receiver/COIL-: C14.2, C15.2, C20.1, D3.2 (A), D5.1 (K), L2.1, TP2.1; also elsewhere on the board
/receiver/VRECT: C16.1, C17.1, C18.1, D1.1 (K), D3.1 (K), D8.1 (K), R13.2, TP8.1; also elsewhere on the board
GND: C16.2, C17.2, C18.2, D2.2 (A), D5.2 (A), D8.2 (A), D11.2 (A), Q1.2 (S), Q2.2 (S), Q3.2 (S), R11.2, TP11.1; also elsewhere on the board
unnamed: C19.2, Q1.3 (D)
unnamed: C20.2, Q2.3 (D)
unnamed: Q3.1 (G), R5.1
unnamed: Q3.3 (D), R4.1

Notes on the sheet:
Botches
47n
31 nF total
To COMP input
Low voltage zener
ASK modulation
IN+
Overvoltage protection
Rectifier
Compensation network
To PA2
15V
44uF
Smoothing
TO CHECK 5V5 ZENER DIODE

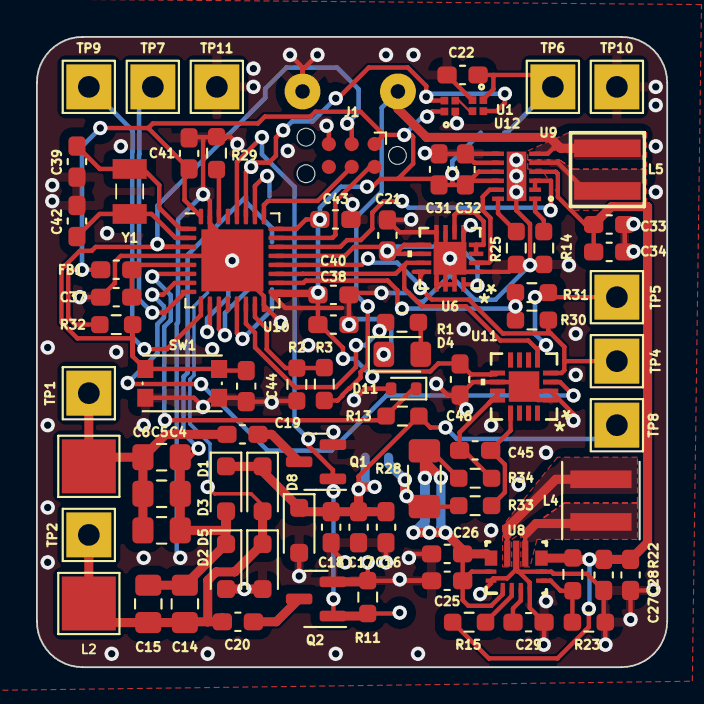
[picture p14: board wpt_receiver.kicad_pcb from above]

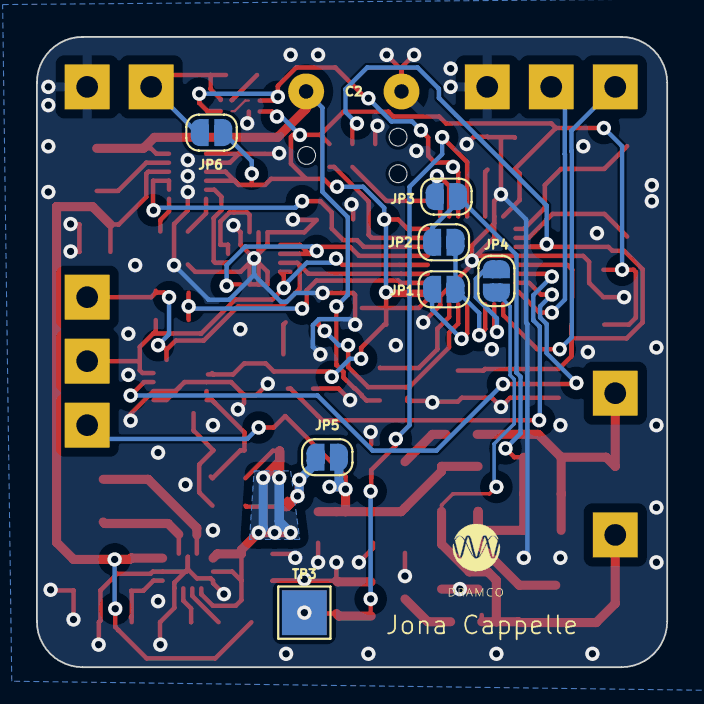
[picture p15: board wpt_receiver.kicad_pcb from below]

Board: 2 copper layers, 35.0 x 35.0 mm, 91 parts (9 on the bottom side), 51 nets.

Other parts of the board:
JP5: SolderJumper_2_Open; SolderJumper-2_P1.3mm_Open_RoundedPad1.0x1.5mm
U4: dramco_logo_small

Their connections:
/power/VRECT: JP5.2 (B); also elsewhere on the board
/receiver/VRECT: JP5.1 (A); also elsewhere on the board

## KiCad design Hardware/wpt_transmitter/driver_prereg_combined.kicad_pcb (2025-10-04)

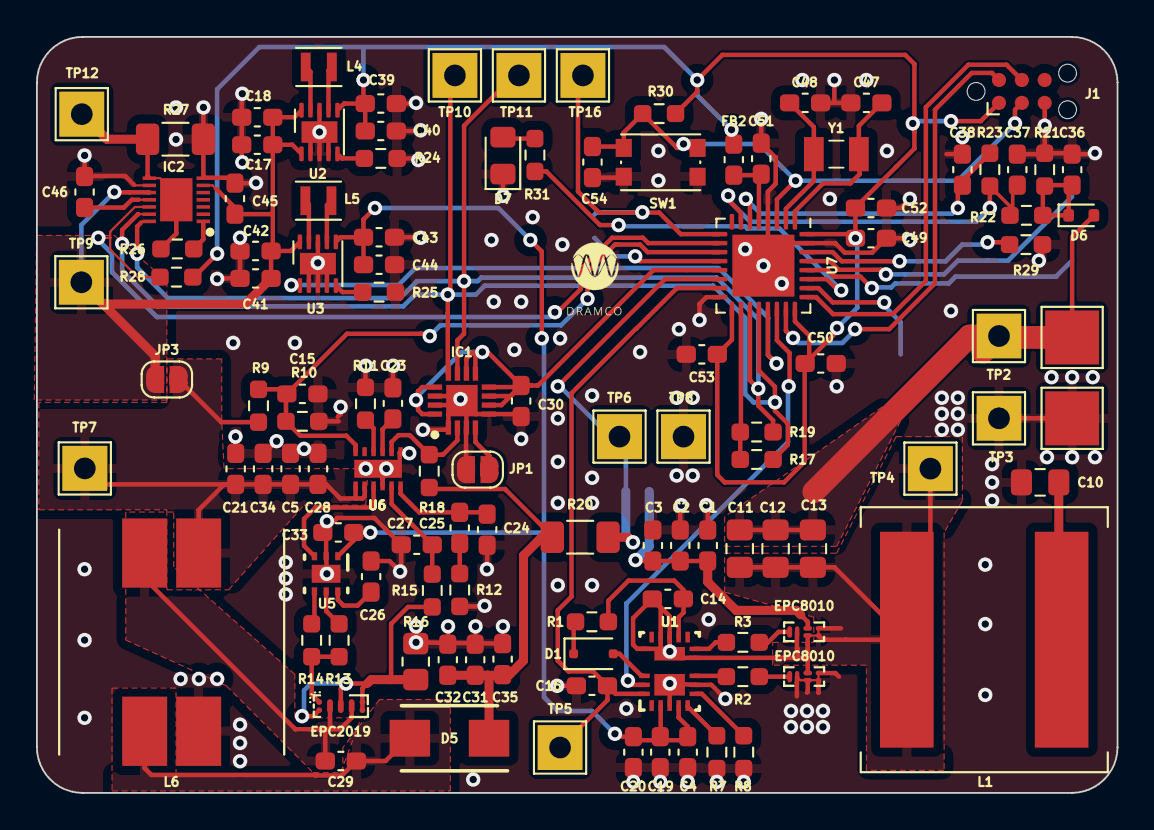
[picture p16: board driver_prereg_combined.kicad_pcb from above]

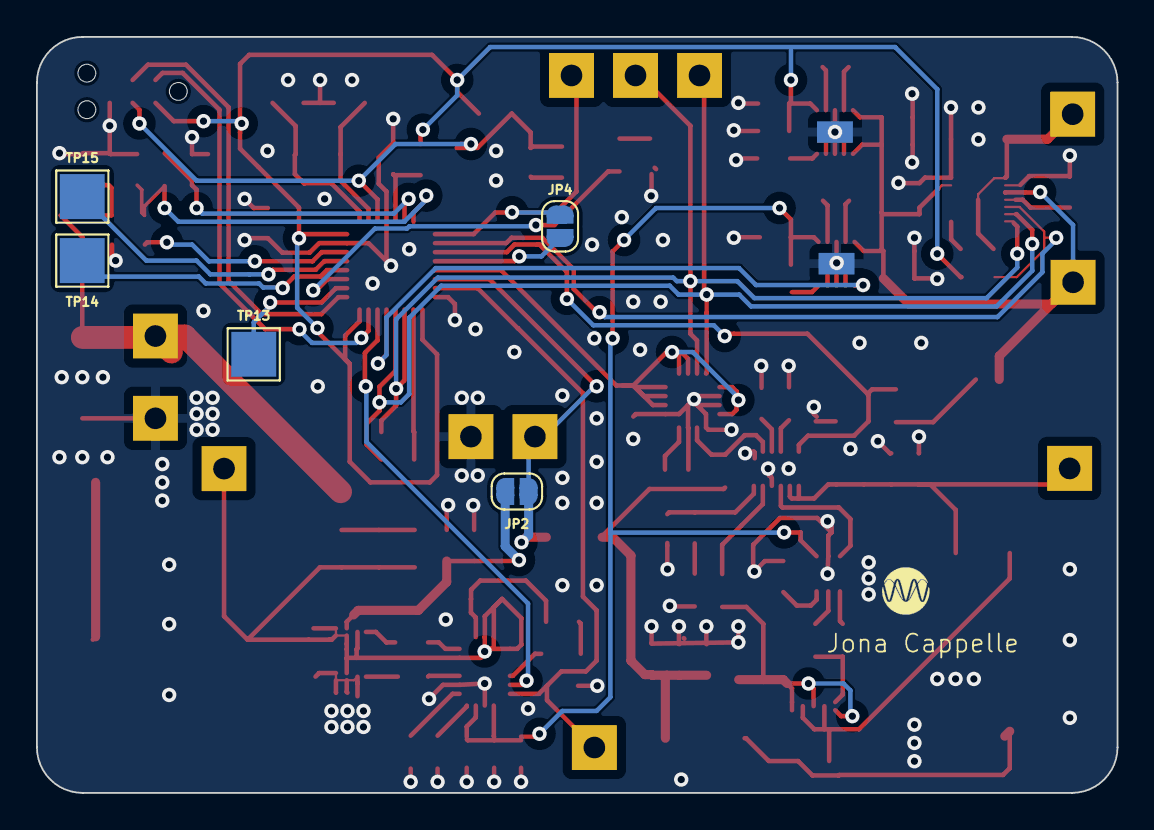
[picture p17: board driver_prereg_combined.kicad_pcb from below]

Board: 2 copper layers, 60.0 x 42.0 mm, 123 parts (7 on the bottom side), 70 nets.

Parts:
C1, C4, C14, C18, C20, C21, C26, C30, C31, C33, C40, C42, C43, C45, C49, C50, C51, C53, C54: 100n; C_0603_1608Metric_Pad1.08x0.95mm_HandSolder
C2, C3, C5, C17, C19, C32, C34, C35, C39, C41, C44: 10u; C_0603_1608Metric_Pad1.08x0.95mm_HandSolder
C10: 1u 50V; C_0805_2012Metric_Pad1.18x1.45mm_HandSolder
C11, C12, C13: 10n; C_0805_2012Metric_Pad1.18x1.45mm_HandSolder
C15, C27, C29: 100p; C_0603_1608Metric_Pad1.08x0.95mm_HandSolder
C16: 22p; C_0603_1608Metric_Pad1.08x0.95mm_HandSolder
C23: 220n; C_0603_1608Metric_Pad1.08x0.95mm_HandSolder
C24: 180p; C_0603_1608Metric_Pad1.08x0.95mm_HandSolder
C25: 680p; C_0603_1608Metric_Pad1.08x0.95mm_HandSolder
C28, C52: 1u; C_0603_1608Metric_Pad1.08x0.95mm_HandSolder
C36, C37, C38, C47, C48: x; C_0603_1608Metric_Pad1.08x0.95mm_HandSolder
C46: 470n; C_0603_1608Metric_Pad1.08x0.95mm_HandSolder
D1: BAT46WJ,115; D_SOD-323F
D5: 755-RB068LB100TBR1; RB068LB100TBR1
D6: 1N4148WS; D_SOD-523
D7: LED; LED_0805_2012Metric_Pad1.15x1.40mm_HandSolder
FB2: 120R; C_0603_1608Metric_Pad1.08x0.95mm_HandSolder
IC1: AD5121BCPZ100-RL7
IC2: MAX17260SETD+; SON40P300X300X80-15N
J1: TC2030_SWD-MCP-NL; Tag-Connect_TC2030-IDC-NL_2x03_P1.27mm_Vertical
JP1, JP2, JP3, JP4: SolderJumper_2_Open; SolderJumper-2_P1.3mm_Open_RoundedPad1.0x1.5mm
L1: x; L_Coilcraft_XAL1350-XXX
L2: 6.8u; Wurth Coil Connector
L4, L5: 2u2; L_Murata_DFE201610P
L6: 744870006; WE-DD_12XX_CROSSED12
Q1, Q2: EPC8010; EPC8000
Q4: EPC2019; EPC2X200M
R1, R13, R14, R15: 100; R_0603_1608Metric_Pad0.98x0.95mm_HandSolder
R2, R3: 0; R_0603_1608Metric_Pad0.98x0.95mm_HandSolder
R7, R8, R10, R17, R19, R28, R29, R30: 10k; R_0603_1608Metric_Pad0.98x0.95mm_HandSolder
R9: 15k; R_0603_1608Metric_Pad0.98x0.95mm_HandSolder
R11: 9.31k; R_0603_1608Metric_Pad0.98x0.95mm_HandSolder
R12: 64.9k; R_0603_1608Metric_Pad0.98x0.95mm_HandSolder
R16: 5.149m; R_0805_2012Metric_Pad1.20x1.40mm_HandSolder
R18: 500k; R_0603_1608Metric_Pad0.98x0.95mm_HandSolder
R20, R27: 20m; R_1206_3216Metric_Pad1.30x1.75mm_HandSolder
R21, R22, R23, R31: x; R_0603_1608Metric_Pad0.98x0.95mm_HandSolder
R24: 16k2; R_0603_1608Metric_Pad0.98x0.95mm_HandSolder
R25: 36k5; R_0603_1608Metric_Pad0.98x0.95mm_HandSolder
R26: 10k NTC; R_0603_1608Metric_Pad0.98x0.95mm_HandSolder
SW1: SW_Push; SW_Push_1P1T_NO_CK_KMR2
TP2: Coil+; TestPoint_THTPad_2.5x2.5mm_Drill1.2mm
TP3: Coil-; TestPoint_THTPad_2.5x2.5mm_Drill1.2mm
TP4: SW; TestPoint_THTPad_2.5x2.5mm_Drill1.2mm
TP5: CLK; TestPoint_THTPad_2.5x2.5mm_Drill1.2mm
TP6: Vout; TestPoint_THTPad_2.5x2.5mm_Drill1.2mm
TP7: Vin; TestPoint_THTPad_2.5x2.5mm_Drill1.2mm
TP8: GND; TestPoint_THTPad_2.5x2.5mm_Drill1.2mm
TP9: Vbat+; TestPoint_THTPad_2.5x2.5mm_Drill1.2mm
TP10: SDA; TestPoint_THTPad_2.5x2.5mm_Drill1.2mm
TP11: SCL; TestPoint_THTPad_2.5x2.5mm_Drill1.2mm
TP12: Vbat-; TestPoint_THTPad_2.5x2.5mm_Drill1.2mm
TP13: TIM22; TestPoint_Pad_2.5x2.5mm
TP14: USART_TX; TestPoint_Pad_2.5x2.5mm
TP15: USART_RX; TestPoint_Pad_2.5x2.5mm
TP16: LPUART_RX; TestPoint_THTPad_2.5x2.5mm_Drill1.2mm
U1: LMG1210RVRR; LMG1210
U2, U3: TPS63900; WSON-10-1EP_2.5x2.5mm_P0.5mm_EP1.2x2mm_ThermalVias
U4, U9: dramco_logo_small
U5: UCC27611DRVR; DRV0006A
U6: LM51561DSSR; DSS0012B
U7: STM32L071KZUx; QFN-32-1EP_5x5mm_P0.5mm_EP3.45x3.45mm
U8: Jona Name
Y1: ABS07-32.768KHZ-7-T; ABS07

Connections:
/ask_demod/COIL_IN: C11.2, C12.2, C13.2, D6.2 (A), L2.1, TP2.1
/ask_demod/COMP+: C37.1, R22.2, R23.1, U7.7 (PA1)
/ask_demod/COMP-: C38.1, R23.2, U7.6 (PA0)
/batt_mgmt/3V3: C39.1, C40.1, C49.1, C50.1, C52.1, C53.1, FB2.1, J1.1 (VCC), R28.1, R30.1, U2.6 (VOUT), U7.17 (VDD), U7.24 (VDDIO2), U7.32 (VDD)
/batt_mgmt/5V: C4.2, C19.1, C20.1, C33.2, C43.1, C44.1, U1.2 (VIN), U1.4 (VCC), U3.6 (VOUT), U5.1 (VDD)
/batt_mgmt/5V_EN: U3.1 (EN), U7.21 (PA11)
/batt_mgmt/ALRT: IC2.12 (ALRT), R28.2, U7.10 (PA4)
/batt_mgmt/SCL: IC1.11 (SCLK/SCL), IC2.14 (SCL), R19.1, TP11.1, U7.19 (PA9)
/batt_mgmt/SDA: IC1.12 (SDI/SDA), IC2.13 (SDA), R17.1, TP10.1, U7.20 (PA10)
/batt_mgmt/V_BAT: C17.1, C18.1, C41.1, C42.1, C45.1, IC2.6 (BATT), IC2.10 (CSPH), JP3.1 (A), TP9.1, U2.1 (EN), U2.10 (VIN), U3.10 (VIN)
/driver/CLK: C16.2, TP5.1, U1.19 (PWM_LI), U7.15 (PB1)
/driver/ENABLE: U1.18 (HI_EN), U7.22 (PA12)
/driver/HB: C14.2, R1.1, U1.12 (HB)
/driver/HS: C11.1, C12.1, C13.1, C14.1, L1.1, Q1.2 (SG), Q1.3 (SP1), Q1.5 (SP2), Q1.6 (Sub), Q2.4 (D), TP4.1, U1.9 (HS), U1.13 (HS), U1.14 (HS), U1.16 (HS), U1.21 (HS_DAP)
/driver/LO: R2.1, U1.8 (LO)
/driver/V_SUPPLY: C1.2, C2.2, C3.2, JP2.2 (B), Q1.4 (D)
/mcu/I2C_EN: R17.2, R19.2, U7.18 (PA8)
/mcu/LED: R31.1, U7.27 (PB5)
/mcu/LPUART_RX: JP4.1 (A), TP16.1, U7.9 (PA3)
/mcu/NRST: C54.1, J1.3 (~RESET), R30.2, SW1.1, U7.3 (NRST)
/mcu/OSC_IN: C47.1, U7.1 (PC14), Y1.1
/mcu/OSC_OUT: C48.1, U7.2 (PC15), Y1.2
/mcu/POT_EN: C30.2, IC1.6 (~SYNC/ADDR0), IC1.7 (~RESET), IC1.8 (DIS), IC1.9 (VDD), IC1.10 (VLOGIC), IC1.13 (~WP), IC1.16 (~LRDAC), U7.13 (PA7)
/mcu/SEPIC_EN: C15.2, R9.1, R10.2, U6.12 (UVLO_SYNC_EN), U7.11 (PA5)
/mcu/SWCLK: J1.4 (SWCLK/TCK), U7.25 (PA14)
/mcu/SWDIO: J1.2 (SWDIO/TMS), U7.23 (PA13)
/mcu/TIM22_CH1_DEBUG: TP13.1, U7.26 (PB4)
/mcu/USART1_RX: TP15.1, U7.29 (PB7)
/mcu/USART1_TX: TP14.1, U7.28 (PB6)
/mcu/V_SEPIC: JP2.1 (A), R20.2, TP6.1, U7.14 (PB0)
/sepic/CS: Q4.2 (S3), Q4.4 (S1), Q4.6 (S2), Q4.7 (Sub), R15.1, R16.2
/sepic/FB: IC1.2 (A), R18.1, U6.8 (FB)
/sepic/GATE: U5.3 (IN+), U6.3 (GATE)
/sepic/GaN FET Vsw: C29.2, L6.2 (1), Q4.3 (D1), Q4.5 (D2)
/sepic/VIN: C5.2, C21.2, C28.2, C34.2, JP3.2 (B), L6.1 (3), R9.2, TP7.1, U6.1 (BIAS), U6.2 (VCC)
/sepic/VOUT1: C31.2, C32.2, C35.2, D5.1 (K), R18.2, R20.1
GND: C1.1, C2.1, C3.1, C4.1, C5.1, C10.2, C15.1, C16.1, C17.2, C18.2, C19.2, C20.2, C21.1, C23.1, C24.1, C26.1, C27.1, C28.1, C30.1, C31.1, C32.1, C33.1, C34.1, C35.1, C36.2, C37.2, C38.2, C39.2, C40.2, C41.2, C42.2, C43.2, C44.2, C45.2, C46.2, C47.2, C48.2, C49.2, C50.2, C51.2, C52.2, C53.2, C54.2, D7.1 (K), IC1.1 (GND), IC1.3 (W), IC1.5 (VSS_1), IC1.14 (SDO/ADDR1), IC1.15 (INDEP), IC1.17 (VSS_2), IC2.7 (CSN), IC2.9 (CSPL), J1.5 (GND), JP1.1 (A), L2.2, L6.4 (2), Q2.2 (SG), Q2.3 (SP1), Q2.5 (SP2), Q2.6 (Sub), R7.1, R8.1, R10.1, R11.1, R12.1, R16.1, R21.2, R24.2, R25.2, R27.2, R29.1, SW1.2, TP3.1, TP8.1, U1.3 (VSS), U1.7 (VSS), U1.20 (LS_DAP), U2.2 (SEL), U2.3 (CFG1), U2.4 (CFG2), U2.8 (GND), U2.11 (GND), U3.2 (SEL), U3.3 (CFG1), U3.4 (CFG2), U3.8 (GND), U3.11 (GND), U5.2 (IN-), U5.7 (PAD), U6.4 (GND), U6.7 (DITHOFF), U6.13 (EP), U7.4 (VSSA), U7.16 (VSS), U7.31 (VSS), U7.33 (VSS)
unnamed: C10.1, L1.2
unnamed: C25.1, R12.2
unnamed: D1.2 (A), U1.17 (BST)
unnamed: D1.1 (K), R1.2
unnamed: C29.1, D5.2 (A), L6.3 (4)
unnamed: C36.1, D6.1 (K), R21.1, R22.1
unnamed: D7.2 (A), R31.2
unnamed: IC1.4 (B), JP1.2 (B)
unnamed: IC2.8 (GND), IC2.15 (EP), R26.2, R27.1, TP12.1
unnamed: C46.1, IC2.11 (REG)
unnamed: IC2.1 (TH), R26.1
unnamed: JP4.2 (B), U7.12 (PA6)
unnamed: Q1.1 (G), R3.2
unnamed: Q2.1 (G), R2.2
unnamed: Q4.1 (G), R13.1, R14.1
unnamed: R7.2, U1.5 (DHL)
unnamed: R8.2, U1.6 (DLH)
unnamed: R3.1, U1.10 (HO)
unnamed: R24.1, U2.5 (CFG3)
unnamed: L4.2, U2.9 (LX1)
unnamed: L4.1, U2.7 (LX2)
unnamed: R25.1, U3.5 (CFG3)
unnamed: L5.2, U3.9 (LX1)
unnamed: L5.1, U3.7 (LX2)
unnamed: R13.2, U5.5 (OUTH)
unnamed: R14.2, U5.4 (OUTL)
unnamed: C26.2, U5.6 (VREF)
unnamed: C24.2, C25.2, U6.6 (COMP)
unnamed: C27.2, R15.2, U6.5 (CS)
unnamed: R11.2, U6.10 (RT)
unnamed: C23.2, U6.9 (SS)
unnamed: R29.2, U7.30 (BOOT0)
unnamed: C51.1, FB2.2, U7.5 (VDDA)

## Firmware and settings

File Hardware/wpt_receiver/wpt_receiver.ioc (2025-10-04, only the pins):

Mcu.UserName=STM32L071KZUx
PA1.GPIO_Label=POWER_ALRT
PA1.Signal=GPIO_Input
PA10.Signal=I2C1_SDA
PA11.GPIO_Label=POT_3V3
PA11.Signal=GPIO_Output
PA12.GPIO_Label=CHG_EN
PA12.Signal=GPIO_Output
PA13.Signal=SYS_SWDIO
PA14.Signal=SYS_SWCLK
PA2.Signal=LPUART1_TX
PA3.Signal=LPUART1_RX
PA4.Signal=COMP2_INM
PA5.Signal=S_TIM2_CH1
PA7.Signal=COMP2_OUT
PA8.GPIO_Label=I2C_enable
PA8.Signal=GPIO_Output
PA9.Signal=I2C1_SCL
PB0.GPIO_Label=LED
PB0.Signal=GPIO_Output
PB1.GPIO_Label=RX_Voltage
PB1.Signal=ADC_IN9
PB4.Signal=COMP2_INP
PB6.Signal=USART1_TX
PB7.Signal=USART1_RX
PC14-OSC32_IN.Signal=RCC_OSC32_IN
PC15-OSC32_OUT.Signal=RCC_OSC32_OUT
